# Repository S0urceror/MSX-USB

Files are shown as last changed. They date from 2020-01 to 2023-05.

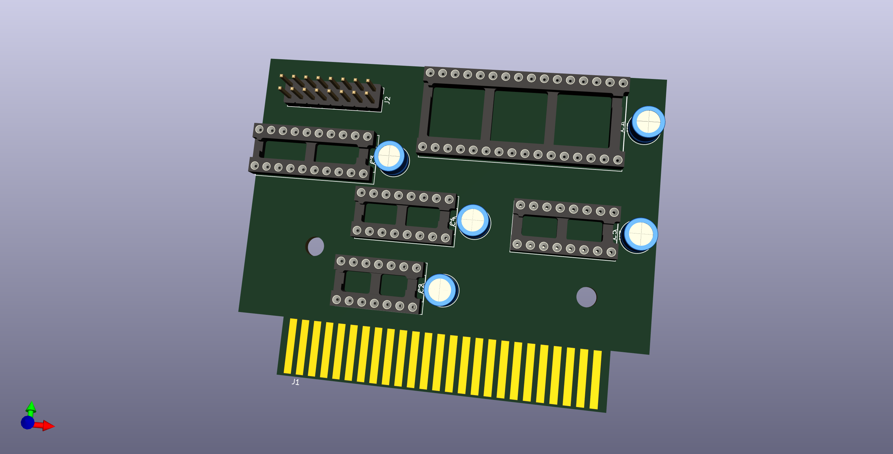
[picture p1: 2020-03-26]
hardware/discontinued/kicad-discrete/MSX USB Drive.png

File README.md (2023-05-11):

# MSX-USB
## Some history
In the 80's the MSX standard was created by Kazuhiko Nishi. He envisioned a simple yet powerful home computer based on standard hardware, software (BIOS/MSX DOS) and connectivity. From 1983 to 1990 manufacturers, like Philips, Sony, Yamaha, Sharp, Canon and many more, made computers according to this standard.

Because of the fact that extensibility was part of the standard people could design cartridges that would add synthesizer sound, memory, modems, rom-based games, or combinations of the above.

Cartridges were connected via a standard 50pin connector that remained the same accross 4 generations of MSX (1/2/2+/TurboR). BIOS and MSX-DOS were designed in a way to discover these via rom-based drivers, software hooks, extended bios.

Standardisation offers a big advantage because everything that adheres to the standard can connect to it.

## USB
USB was designed in the 90's to do something similar. To standardize the connection of peripherals to personal computers, both to communicate with and to supply electric power. It has now largely replaced interfaces such as serial ports and parallel ports, and has become commonplace on a wide range of devices. Like USB flash drives, keyboards, mice, wifi, serial, camera's, etc.

What if the MSX would have an USB connection? And if the BIOS/MSX DOS would automatically recognize devices connected to it?

## Meet MSX-USB
Inspired by the work of Xavirompe and his [RookieDrive](http://rookiedrive.com/en/) I set out to do exactly this. And since I'm a big believer of open standards and open source I'm opening up my work to everyone.

On this GitHub page you can find:
* Schematics (KiCAD), that interfaces a cheap USB CH376s board to the MSX cartridge port.
* Drivers, currently Flash drives on Nextor and HID keyboards are supported.
* Debugging tools, to connect a test board to your PC/MAC and assist in debugging.

On my GitHub I also have forks of OpenMSX and CocoaMSX that either emulate or connect to a test board via serial to assist in development and debugging.

## Schematics
This connects the CH376s board you can find on eBay or AliExpress for around 4 Euro to the MSX. 

Circuitry is added to correctly handle the _BUSDIR signal. Make sure you select parallel by setting the jumper on the CH376s board correctly.

The CH376s board will be visible on port 10h and 11h on the MSX. Port 11h is the command port and 10h is the data port. Specifics on how to program for the CH376s are scattered around the Internet:
* https://www.mpja.com/download/ch376ds1.pdf
* https://arduinobasics.blogspot.com/2015/05/ch376s-usb-readwrite-module.html

Most information is available on how to use the higher-order API for flash drives. 

If you want to use other USB devices you have to go low-level. As it turns out Konamiman already did some work there and after some researching I got USB HID Keyboards, Ethernet, Serial working as well. Check out my source-code or these great pages for more information:
* http://www.usbmadesimple.co.uk/index.html
* https://www.beyondlogic.org/usbnutshell/usb1.shtml

## PCB
Please use the rev4 PCB by @cristianoag. This fits in a Konami style cartridge case and has a switch to select between two ROM images. Also use the rev4 CPLD code to enable this feature.

## UNAPI USB
I wrote a UNAPI USB specification and implemented the Usb Host driver according to this. The next version of this Host driver will also implement the Usb Hub specification and enumerate and initialise all devices connected.

## USB HID Keyboard
The Usb Keyboard driver connects to Unapi Usb driver and hooks itself to H.CHGE. From that moment on it replaces your trusted MSX keyboard by a shiny new USB Keyboard. Or a wireless one if you have inserted the appropriate Logitech receiver.

## USB CDC ECM Ethernet
The USB CDC ECM Ethernet driver is finished. It uses the Unapi USB and conforms to the Unapi Ethernet standard. Internestor Lite can now connect and use your USB Ethernet device. Please note that currently we only support USB CDC ECM. Make sure your Ethernet device supports this.

All USB Ethernet devices built around the **RTL8153** chipset support USB CDC ECM. They usually cost around 20 euro.

## USB Storage
A low level USB driver is created to connect to storage devices like thumb drives, portable hard disks, etc. 

## USB Hub
The USB Hub driver will interrogate an USB Hub and all devices connected to it.

# Installation instructions
Check [this page](INSTALL.md) for installation instructions and links to the various binaries that have been developed.

# Build your own (DIY)
Check [this page](DIY.md) for information on how to make the PCB, program the CPLD device, flash the ROM, etc.

# Collaboration
Do you want to help with the development of MSX USB? Write drivers for other devices? Or contribute in other ways?

Please drop me line on sourceror at neximus.nl or meet me on the msx.org forum.

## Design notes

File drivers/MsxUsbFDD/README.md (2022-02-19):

## Usage
This is a Nextor driver programmed in C. It mounts the USB disk connected to the MSXUSB cartridge. Other devices and USB hubs are not supported by this driver.

### Disk formats supported
1. FAT32
    - Format in Windows, MacOS, Linux with master boot record. 
    - Place .DSK floppy images in the root folder or subfolders. 
    - Select the right DSK file during MSX boot.
2. FAT16
    - Format in Windows, MacOS, Linux with master boot record. 
    - Place .DSK floppy images in the root folder or subfolders. 
    - Select the right DSK file during MSX boot. 
    - **NEXTOR can also mount the whole USB drive in FAT16 mode**
3. FAT12
    - Format in MacOS, Linux or by DD-ing a DSK file to the USB drive. 
    - You will waste a lot of space because now the USB drive can only contain 720kb.

### MSX compatibility
On MSX 1 you can only mount FAT12 720kb DSK images. On MSX 2 and higher you can mount FAT16 DSK images of various sizes or the whole USB disk when formatted in FAT16.

### AUTOEXEC.DSK
Place a disk image called AUTOEXEC.DSK in the root of the USB drive to mount this image automatically. If your press ESCape within 3 seconds it will show the normal boot menu.

### CALL MOUNTDSK
In MSX Basic you can use the _MOUNTDSK or CALL MOUNTDSK command to show the boot menu again and change to another DSK image. Just like changing a floppy would.

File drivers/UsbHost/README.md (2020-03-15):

# USB - Host UNAPI DRIVER
Below the specification of an UNAPI compliant USB driver. Other, more specialised, drivers can rely on this base driver to return the basic information and low-level routines.

## API Information Routine (UNAPI:0)
```
Input: A = 0

Output:
* HL = Address of the implementation name string
* DE = API specification version supported. D=primary, E=secondary.
* BC = API implementation version. B=primary, C=secondary.
```

## JumpTable (UNAPI:1)
This function will return the jumptable to the USB functions to be directly called. 
Every jumptable entry of 8 bytes has the following proposed format. 
Although this can be changed by the UNAPI driver if necessary.
```
Input: A = 1
       HL = pointer to buffer to receive the jumptable
```
UNAPI in ROM:
```
00: RST 30h
01: DB SlotID
02: DW Address
04: RET
05: NOP
06: NOP
07: NOP
```
UNAPI in MemoryMapper:
```
00: CALL CALLS
03: DB Segment
04: DW Address
06: RET
07: NOP
```
Or in PAGE 3:
```
00: JP Address
03: NOP
04: NOP
05: NOP
06: NOP
07: NOP
```
### The functions returned are:
To call a function just do a call to one of the addresses in the jumptable.
Drivers are specifically written to be in ROM, Mapped Ram or Page 3. 
By using this jump table approach, the burden for handling all the specific cases is shifted back from the client to the driver itself. 
This is contrary to the initial UNAPI approach where slot, segment, address is returned by the EXTBIO call, and it is expected by the client to adapt to this.
```
HL+0000: Check
HL+0008: Connect
HL+0010: GetDescriptors
HL+0018: ExecuteControlTransfer
HL+0020: DataInTransfer
HL+0028: DataOutTransfer
HL+0030: ScratchArea
HL+0038: SetNAKRetry
```
## Check (UNAPI:2/JT:00h)
Check if specialised USB hardware is present, like RookieDrive or MSXUSB cartridge.
```
Input:  A = 2
Output: Cy = 0, everything okay, Cy = 1, adapter not ready
```

## Connect (UNAPI:3/JT:08h)
Connect the inserted USB device, reset it properly and prepare for communication.
```
Input:  A = 3
Output: Cy = 0, everything okay, Cy = 1, device not connected
```

## GetDescriptors (UNAPI:4/JT:10h)
Return both the fixed length DEVICE_DESCRIPTOR followed by the variable length CONFIGURATION_DESCRIPTOR containing INTERFACE_DESCRIPTORS, ENDPOINT_DESCRIPTORS and specialised descriptors for HID, CDC ECM, etc.
```
Input: A = 4
       HL = buffer to hold the descriptor information
```

## ExecuteControlTransfer (JT:18h)
Perform a USB control transfer on endpoint 0. The size and direction of the transfer are taken from the contents of the setup packet.
```
Input:  HL = Address of a 8 byte buffer with the setup packet
        DE = Address of the input or output data buffer
        A  = Device address
        B  = Maximum packet size for endpoint 0
Output: A  = USB error code
        BC = Amount of data actually transferred (if IN transfer and no error)
```
## DataInTransfer (JT:20h)
Perform a USB data IN transfer.
```
Input:  HL = Address of a buffer for the received data
        BC = Data length
        A  = Device address
        D  = Maximum packet size for the endpoint
        E  = Endpoint number
        Cy = Current state of the toggle bit
Output: A  = USB error code
        BC = Amount of data actually received (only if no error)
        Cy = New state of the toggle bit (even on error)
```
## DataOutTransfer (JT:28h)
Perform a USB data OUT transfer.
```
Input:  HL = Address of a buffer for the data to be sent
        BC = Data length
        A  = Device address
        D  = Maximum packet size for the endpoint
        E  = Endpoint number
        Cy = Current state of the toggle bit
Output: A  = USB error code
        Cy = New state of the toggle bit (even on error)
```
## ScratchArea (JT:30h)
Get a pointer to the scratch area allocated by moving HIMEM down. Scratch area is used to store USB command packages and a bit of reserved space.
```
Input:  BC = delta in bytes should >0 and < size of scratch area (8*8 bytes currently)
Output: HL = pointer to scratch area in page 3
```

## SetNAKRetry (JT:38h)
Tell USB interface how to handle NAK's. NAK's mostly happen when the device is not yet ready. 
By default the CH376s hardware will automatically retry NAK's until the device is ready and gives back the requested data. But what if the device takes a long time? This will potentially lead to a blocking operation. If you want to avoid this you can set retry's to off or to 3 seconds.
```
Input:  A = retry mode
        Bits 7 and 6:
          0x: Don't retry NAKs
          10: Retry NAKs indefinitely (default)
          11: Retry NAKs for 3s
        Bits 5-0: Number of retries after device timeout
        Default after reset and SET_USB_MODE is 8Fh
Output: (none)
```

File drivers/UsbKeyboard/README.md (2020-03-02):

# Usb Keyboard
The USB Keyboard driver will automatically find the Unapi Usb driver and connect with it. It then checks if a HID compliant keyboard is connected. After that it will start it's resident portion that hooks itself to H.CHGE.

After this the keyboard will work within Basic and DOS and will replace the built-in keyboard. 
Software (games) that don't use BIOS for keyboard will continue to work on the built-in keyboard of the MSX.

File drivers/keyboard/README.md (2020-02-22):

# USB-HID-MSX - MSX driver for USB HID keyboards

USB-HID uses low level execute-command sequences for all common USB and USB HID communication via CH376.

Load the current version via BLOAD "driver.bin",r

It will find the connected USB HID keyboard, activate it's BOOT protocol, and installs the H.CHGE hook. After this the normal keyboard won't work anymore. The HID keyboard takes over. 

When you press ALT+Q the hook is deinstalled and the MSX keyboard works again.

## Limitations
* special keys like STOP and GRAPH not yet implemented
* should automatically start with the computer from ROM
* work in progress...

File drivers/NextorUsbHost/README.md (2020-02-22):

# USB Flash Drive
Once flashed Nextor ROM will automatically find the driver and initialise the CH376s.
Then it searches the file identified by TXT_NEXTOR_DSK and mounts it. 
It then continuous to boot. 
* If there is NEXTOR.SYS and COMMAND2.COM on the mounted disk it will start NEXTOR.
* If there is MSXDOS2.SYS and COMMAND2.COM on the mounted disk it will start MSXDOS2.x
* If there is MSXDOS.SYS and COMMAND.COM it will start MSXDOS1.x
* Otherwise it goes to MSX BASIC

In MSX Basic you have the following commands:
* CALL USBFILES - list all files in the current directory of the FAT32 formatted flash drive
* CALL USBCD - change to another directory of the flash drive
* CALL INSERTDISK ("filename.ext") - load another disk image and mount it
* CALL EJECTDISK - eject the current mounted disk image

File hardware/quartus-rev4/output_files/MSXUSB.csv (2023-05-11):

# Copyright (C) 1991-2011 Altera Corporation
# Your use of Altera Corporation's design tools | logic functions
# and other software and tools | and its AMPP partner logic
# functions | and any output files from any of the foregoing
# (including device programming or simulation files) | and any
# associated documentation or information are expressly subject
# to the terms and conditions of the Altera Program License
# Subscription Agreement | Altera MegaCore Function License
# Agreement | or other applicable license agreement | including
# without limitation | that your use is for the sole purpose of
# programming logic devices manufactured by Altera and sold by
# Altera or its authorized distributors. Please refer to the
# applicable agreement for further details.
# Quartus II Version 11.0 Build 208 07/03/2011 Service Pack 1 SJ Web Edition
# File: C:/Users/crist/OneDrive/Personal/11. Electronics/MSXUSB/GitHub/MSX-USB.crisag/hardware/quartus-rev3/output_files/MSXUSB.csv
# Generated on: Wed Nov 23 20:26:52 2022
# Note: The column header names should not be changed if you wish to import this .csv file into the Quartus II software.
To | Direction | Location | Reserved
TCK | Input
TDI | Input
TDO | Output
TMS | Input
busdir | Output | PIN_6
cs_ch376s_n | Output | PIN_5
data[5] | Input | PIN_8
data[4] | Input | PIN_9
data[3] | Input | PIN_11
data[2] | Input | PIN_12
data[1] | Input | PIN_14
data[0] | Input | PIN_16
in_a7_a0[7] | Input | PIN_18
in_a7_a0[6] | Input | PIN_19
in_a7_a0[5] | Input | PIN_20
in_a7_a0[4] | Input | PIN_21
in_a7_a0[3] | Input | PIN_24
in_a7_a0[2] | Input | PIN_25
in_a7_a0[1] | Input | PIN_26
in_a7_a0[0] | Input | PIN_27
in_a15_a13_a12[2] | Input | PIN_28
in_a15_a13_a12[1] | Input | PIN_29
in_a15_a13_a12[0] | Input | PIN_17
iorq_n | Input | PIN_4
out_a13_a18[5] | Output | PIN_31
out_a13_a18[4] | Output | PIN_33
out_a13_a18[3] | Output | PIN_34
out_a13_a18[2] | Output | PIN_36
out_a13_a18[1] | Output | PIN_37
out_a13_a18[0] | Output | PIN_39
rd_n | Input | PIN_1
reset_n | Input | PIN_44
rom_sl | Input | PIN_2
sltsl_n | Input | PIN_41
wr_n | Input | PIN_40

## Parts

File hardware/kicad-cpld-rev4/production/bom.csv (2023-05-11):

Designator | Footprint | Quantity | Value | LCSC Part #
C1 | CP_Radial_D5.0mm_P2.50mm | 1 | 100 uF
C2, C3, C4 | C_0805_2012Metric_Pad1.18x1.45mm_HandSolder | 3 | 0.1 uF
EDG1 | msx-con-MSXCART | 1 | MSX_CON
J1 | PinHeader_2x05_P2.54mm_Vertical | 1 | AVR-JTAG-10
J2 | PinHeader_2x08_P2.54mm_Vertical | 1 | Conn_02x08_Odd_Even
LOGO_MSX | LOGO_MSX | 1
R1 | R_0805_2012Metric_Pad1.20x1.40mm_HandSolder | 1 | 4K7
SW1 | SK12D07VG4 | 1 | SK12D07VG4
U1 | PLCC44 | 1 | EPM7032_7064
U2 | PLCC-32_THT-Socket | 1 | AM29f040

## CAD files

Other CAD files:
hardware/quartus-rev4/simulation/modelsim/rtl_work/ch376/verilog.psm
hardware/quartus-rev4/simulation/modelsim/rtl_work/msxusb/verilog.psm
hardware/quartus-rev4/simulation/modelsim/rtl_work/scc_rom_mapper/verilog.psm
hardware/quartus-rev4/simulation/modelsim/rtl_work/t_ch376/verilog.psm
hardware/quartus-rev4/simulation/modelsim/rtl_work/t_scc_rom_mapper/verilog.psm

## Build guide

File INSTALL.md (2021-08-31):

# MSX-USB
## Installation instructions
You have to flash a new NEXTOR ROM image onto a MSX flash cartridge. The RookieDrive and other MSX USB initiatives have both Flash and the USB part combined in one cartridge so thats easy. In my prototype setup I have one cartridge with MSX USB and one modded SCC cartridge with flash and that works as well.

You can use the MSX USB cartridge in two modes.

### Use as disk drive
* Download [this](https://github.com/S0urceror/MSX-USB/raw/master/drivers/NextorUsbHost/dist/nextor.rom) ROM image
* Flash the image
* Reboot

The first time you need to boot up with a floppy disk with the NEXTOR.SYS and COMMAND2.COM files. 
Please insert a FAT16 formatted USB Flash Disk in the MSX USB cartridge.
Put NEXTOR.SYS and COMMAND2.COM in the root of that disk. Insert into the MSX and go.

*N.B. if you want to use MSXUSB on the [RookieDrive](http://rookiedrive.com/en/) please use [this](https://github.com/S0urceror/MSX-USB/raw/master/drivers/NextorUsbHost/dist/nextorrd.rom) version of the ROM.*

### Multi purpose USB port
The ROM image now also contains an UNAPI compatible USB Host driver.

You can do the following things:
* [APILIST.COM](https://github.com/S0urceror/MSX-USB/raw/master/drivers/UsbEthernet/dist/apilist.com) MSXUSB to check that the UNAPI driver is ready and works.
* [LSUSB.COM](https://github.com/S0urceror/MSX-USB/raw/master/drivers/UsbEthernet/dist/lsusb.com) to list all technical USB information from the connected USB device.
* [USBETHER.COM](https://github.com/S0urceror/MSX-USB/blob/master/drivers/UsbEthernet/dist/usbether.com) to install the USB Ethernet Driver. You can then subsequently run `INL i` to install Internestor Lite. When all goes well you can then run any TCP/IP applications like `TELNET`, `HUB`, `HGET`, `TFTP`, etc. More information about this you can find on [Konamiman's](https://www.konamiman.com/msx/msx-e.html#inl2) website.
* BLOAD ("[USBKEYBD.BIN](https://github.com/S0urceror/MSX-USB/raw/master/drivers/UsbKeyboard/dist/usbkeybd.bin)"),R to install the USB HID Keyboard driver. This will enable any connected USB HID compliant keyboard.

## Flashing the image
To flash the ROM's you need an appropriate flashing tool. For this I created a program called Flash. You can download it [here](https://github.com/S0urceror/MSX-USB/raw/master/software/dist/flash.com)

It is simple to use Flash. The following statement automatically finds the (mega-)flash cartridge and flashes image.rom.

`FLASH nextor.rom`

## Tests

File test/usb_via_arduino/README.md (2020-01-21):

# usb-hid
USB-HID uses low level execute-command sequences for all common USB and USB HID communication via CH376. 

The CH376s has higher level commands for GET_DESCRIPTOR, SET_ADDRESS but they are limited to 64 byte packet-size.
By using low-level command sequences we can read the larger  descriptors that are typical for HID devices. 
Particulary the Logitech USB Receivers that I intend to use.

Is currently able to discover attached keyboards and mice.

This simple C/C++ program is just a tester to move this functionality to a MSX driver. 
Yes, this illustrious computing system from the 80's finally gets USB connectivity.

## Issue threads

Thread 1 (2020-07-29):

Fail Rom flash AM29F040

retrocant, 2020-07-29:
Greetings, I am having problems recording the msx-usb flashrom, it gives me the following error:

MSXUSB Flash, (c) 202 S0urceror

M: E5, D: CD
M: CD, D: AB
M: F0, D: 1F
M: FF, D: FF

cannot find slot with flash

I am doing the flash method through the MegaFlashrom

S0urceror, 2020-07-29:
Hi Retrocant,

My routine expects to find:

// Am29F040B = A4

// M29F800AB = 58

// SST39SF040 = B7

These are all 4Mbit/512KB flash ROM’s. Could be that you have the AM29F400BB that has device code ‘AB’ in your 2nd line.

To force flashing on slot 1 use:

flash.com /S1 [filename]

Can you confirm it works then I’ll add AB to my identification routine.

Thanks,

S0urceror

From: retrocant <notifications@github.com>
Reply to: S0urceror/MSX-USB <reply@reply.github.com>
Date: Wednesday, 29 July 2020 at 17:00
To: S0urceror/MSX-USB <MSX-USB@noreply.github.com>
Cc: Subscribed <subscribed@noreply.github.com>
Subject: [S0urceror/MSX-USB] Fail Rom flash AM29F040 (#1)

Greetings, I am having problems recording the msx-usb flashrom, it gives me the following error:

MSXUSB Flash, (c) 202 S0urceror

M: E5, D: CD
M: CD, D: AB
M: F0, D: 1F
M: FF, D: FF

cannot find slot with flash

I am doing the flash method through the MegaFlashrom

—
You are receiving this because you are subscribed to this thread.
Reply to this email directly, view it on GitHub, or unsubscribe.

retrocant, 2020-07-30:
Greetings, I already did the flash / s1 NEXTOR.ROM routine and it doesn't work either, it gives me the same error.

Greetings.

S0urceror, 2020-07-30:
Which MSXUSB cartridge did you make? The CPLD version? Did you use the latest design or the first design? The first design had two issues that you can easily solve with a couple of wires.

On the other hand what type/version of Flash chip have you installed? The AM29F040?

If you have the RookieDrive make sure you use the flash tool that came with that cartridge because it uses another ROM mapper and other Flash chip.

From: retrocant <notifications@github.com>
Reply to: S0urceror/MSX-USB <reply@reply.github.com>
Date: Thursday, 30 July 2020 at 18:18
To: S0urceror/MSX-USB <MSX-USB@noreply.github.com>
Cc: Mario Smit <mario.smit.nl@gmail.com>, Comment <comment@noreply.github.com>
Subject: Re: [S0urceror/MSX-USB] Fail Rom flash AM29F040 (#1)

Greetings, I already did the flash / s1 NEXTOR.ROM routine and it doesn't work either, it gives me the same error.

Greetings.

—
You are receiving this because you commented.
Reply to this email directly, view it on GitHub<https://github.com/S0urceror/MSX-USB/issues/1#issuecomment-666501659>, or unsubscribe<https://github.com/notifications/unsubscribe-auth/ABGC6KCOS5NVSOIFTGZYSLTR6GMOBANCNFSM4PLV7PHQ>.

retrocant, 2020-07-31:
Greetings, I have the CPLD version, I don't know if there were two different versions in that version ... how could I know?

I use FLASH AM29F040

retrocant, 2020-07-31:
I just made the two bridges for the SLTSL and RD and it keeps giving me the same error, it doesn't flash me

S0urceror, 2020-08-02:
Your PCB is the rev.1 version. There were two flaws in this. One was with RD and SLTSL reversed. The other was that A12 was not connected to the CPLD.

Have you also have created an extra bridge between Flash pin 4 and CPLD pin 17?

From: retrocant <notifications@github.com>
Reply to: S0urceror/MSX-USB <reply@reply.github.com>
Date: Friday, 31 July 2020 at 19:51
To: S0urceror/MSX-USB <MSX-USB@noreply.github.com>
Cc: Mario Smit <mario.smit.nl@gmail.com>, Comment <comment@noreply.github.com>
Subject: Re: [S0urceror/MSX-USB] Fail Rom flash AM29F040 (#1)

I just made the two bridges for the SLTSL and RD and it keeps giving me the same error, it doesn't flash me

—
You are receiving this because you commented.
Reply to this email directly, view it on GitHub<https://github.com/S0urceror/MSX-USB/issues/1#issuecomment-667252912>, or unsubscribe<https://github.com/notifications/unsubscribe-auth/ABGC6KC3DYDCCSX43HZXVRLR6MADHANCNFSM4PLV7PHQ>.

retrocant, 2020-08-06:
Greetings, I already made the bridge in the CPLD and it works, I did not know about that bridge, I have it functional.

Now I have a question, there are two versions 0.5 and 0. release.

I have an 8GB FAT32 USB flash drive, version 0.5 works fine and it recognizes the flash drive, but version 0.6 does not recognize the USB.

S0urceror, 2020-08-07:
Hi Retrocant,

Glad and good to hear that you have it working!

Until 0.5 the driver used the built-in FAT32 support of the CH376s chip. Starting 0.6 I implemented a low-level USB storage driver that also works behind an USB Hub. Now I have to rely on the FAT16 support of Nextor instead. If you reformat your drive to FAT16 it will work again with the added bonus it will also work on a Hub together with other USB devices.

That said, I could check what you have connected, if you have directly connected a USB storage device with FAT32, use the built-in driver, or otherwise fallback on my own storage driver that supports Hubs with FAT16. Would be a nice feature for a next release.

Regards,

Mario

From: retrocant <notifications@github.com>
Reply to: S0urceror/MSX-USB <reply@reply.github.com>
Date: Thursday, 6 August 2020 at 20:11
To: S0urceror/MSX-USB <MSX-USB@noreply.github.com>
Cc: Mario Smit <mario.smit.nl@gmail.com>, Comment <comment@noreply.github.com>
Subject: Re: [S0urceror/MSX-USB] Fail Rom flash AM29F040 (#1)

Greetings, I already made the bridge in the CPLD and it works, I did not know about that bridge, I have it functional.

Now I have a question, there are two versions 0.5 and 0. release.

I have an 8GB FAT32 USB flash drive, version 0.5 works fine and it recognizes the flash drive, but version 0.6 does not recognize the USB.

—
You are receiving this because you commented.
Reply to this email directly, view it on GitHub<https://github.com/S0urceror/MSX-USB/issues/1#issuecomment-670092006>, or unsubscribe<https://github.com/notifications/unsubscribe-auth/ABGC6KEELN3MDLWHQJRXGH3R7LW35ANCNFSM4PLV7PHQ>.

S0urceror, 2021-09-07:
Closing this issue, good that we traced the problem down to the reversed OE (output enable) and CE (chip enable). The latest published PCB with the clearly marked v1.0 on the silkscreen does not have this problem.

issalig, 2022-02-19:
I cannot make it work. Tested on MSX1 VG-8020  with a pcb v1.0 and also other people reported similar problem with MSX2 f9s

I use a SST39SF040 which should give id BF B7 and I am getting these values

E5 CD
41, 42
41, 42
F0, 0

I checked the codes on http://www.cnc-lab.com/idcodes.txt and they does not seem to fit any IC.

Any idea?

S0urceror, 2022-02-19:
Hi Issalig,

I made an earlier mistake in my PCB which I corrected in an updated design pushed to GitHub.

SLTSL from the cartridge port should be connected to CE (pin 22) and RD from the cartridge port should be connected to OE (pin 24) of the flash chip. Can you verify this with a multi-meter?

You now get 0x41,0x42 on slot 1 and 2. This means there are MSX roms read. A flash however should respond with the manufacturer codes which it doesn’t do now.

Let me know the result.

Regards,

Mario

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

issalig, 2022-02-19:
pcb is ok. CE nad OE are connected to SLTSL and RD

I tried to change bytecodes
AM takes 0x555 and 0x2aa
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

and SST 0x5555 and 0x2aaa
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

Results are different now, but still does not work
E5 CD
FE, 5E    <---- this was 41,42, the others are the same
41, 42
F0, 0

S0urceror, 2022-02-20:
You’re on the right path.

Can’t test it here but if you:

  *   Change the __at 0x4000 statement to __at 0x0000 at line 30.
  *   Update all places where flash_segment is used with the right addresses.
  *   Write 0xAA to flash_segment[0x5555]
  *   Write 0x55 to flash_segment[0x2AAA]
  *   Write 0x90 to flash_segment[0x5555]
  *   Read manufacturer from flash_segment[0x0000]
  *   Read device from flash_segment[0x0000]

Then it should show you 0xBF, 0xB5 respectively.

Also the erase and flash routines have to be updated with the other addresses.

P.S. would be great to have all this governed by #defines and -D arguments in the Makefile. This way we can make multiple versions of the flash.com program each for every flash chip.

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

issalig, 2022-02-20:
Changing to 0x0000 and new adresses does not help. It prints the first 2 slots, then hangs for a little bit and restarts system without detecting msxusb

F0, D3
F0, D3
...
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
issalig, 2022-02-24:
Thanks for the explanation. I am getting a better picture of the situation and I did the changes but the code does not still work and it hangs when scanning slot 2.

Let's try to understand it, flash_segment points to address 0x4000 (page 1, after system rom).
Next, select_slot_40 selects page 1 on slot i, that means we have access to flash chip on msx memory addresses 4000-7ffff
The same is done for slot_80 and msx addresses 8000-BF000

So flash_segment[0] points to 0x4000 that itself points to 0x4000 in slot i (aka our cartridge).

We need to access flash address 0x5555 which resides in the page 1 (4000-7fff) and flash_segment points to 4000. Would not flash_segment[0x1555] be the indirect address to arrive to internal 0x5555 ?

If this is correct, then 0x2aaa could not be reached but I am almost sure I misunderstood sth.

S0urceror, 2022-02-24:
I am commenting below:

> Let's try to understand it, flash_segment points to address 0x4000 (page 1, after system rom). Next, select_slot_40 selects page 1 on slot i, that means we have access to flash chip on msx memory addresses 4000-7ffff The same is done for slot_80 and msx addresses 8000-BF000

That is correct.

> So flash_segment[0] points to 0x4000 that itself points to 0x4000 in slot i (aka our cartridge).

It points indeed to 0x4000 to slot i. But what ROM page is mapped there? That depends on a previous write to 0x5000. This triggers the FPGA to select page 0 which is address range 0x00000 to 0x04000. So from now on a write to a CPU address of 0x6aaa is actually targeting flash address 0x02aaa.

> We need to access flash address 0x5555 which resides in the page 1 (4000-7fff) and flash_segment points to 4000. Would not flash_segment[0x1555] be the indirect address to arrive to internal 0x5555 ?

If as stated above the CPU address range 0x4000 to 0x7fff points to page 0 being flash range 0x00000 to 0x03fff and we make sure that CPU address range 0x8000 to 0xbfff points to page 1 being flash range 0x04000 to 0x07fff. Then we need to write to CPU address 0x9555 to write to flash address 0x05555.

I'll try to test the above theory out and report back. This would enable you to address 32k of the flash and reach all the addresses the flash-ident and flash-write routines need to function.

issalig, 2022-02-26:
Looking at the verilog scc code I see that when a write is detected, the values of a15,a13,a12  establish the following addresses.
| A15 | A14 | A3 | A12 |
|  0    |  ?    |   0  |     1  |   1XXX, 5XXX
|  0    |  ?    |   1  |     1  |   3XXX , 7XXX
|  1    |  ?    |   0  |     1  |   9XXX , DXXX
|  1    |  ?    |   1  |     1  |   BXXX , FXXX

In a similar way a read gives

| A15 | A14 | A3 | A12 |
|  0    |  ?    |   0  |     ?  |   0XXX, 1XXX*, 4XXX, 5XXX*
|  0    |  ?    |   1  |     ?  |   2XXX , 3XXX*, 6XXX, 7XXX*
|  1    |  ?    |   0  |     ?  |   8XXX , 9XXX*, CXXX, DXXX*
|  1    |  ?    |   1  |     ?  |   AXXX , BXXX*, EXXX, FXXX*

(*) the ones for write.

So for example a write to 0x5000=0 will put mem0 into address_upper and data into mem0
address_upper are the pins A18-A13   and data will be 0 in this case.

```
case(a15_a13_a12[2:1])
			2'b00: address_upper = mem0;
```
```
case(a15_a13_a12)
   3'b001: mem0 = data;
```
I checked the addresses below with the ones in https://www.msx.org/wiki/MegaROM_Mappers#Konami.27s_MegaROMs_with_SCC
and I am lost at this point. I must find some documentation for dummies because reverse engineering this from code will take me years.

Closed 2021-09-07.

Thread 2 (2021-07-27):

Minified pcb (my build log)

issalig, 2021-07-27:
Hi, thanks for sharing the project. I am new to the MSX world and I am working on a minified pcb with plcc sockets and exposed headers for future developement (as soon as everything works I will update my fork). Board will be 5 cm high.

I have some doubts about the bill of materials, the cpld is epm7064 or epm7032? SLC44 or LC44?
The memory could it be SST39SF040-70 or  SST39SF040-55?

Maybe there is a BOM file and I did not find but it would be nice to have it also with some alternative components.

Thanks in advance

S0urceror, 2021-07-28:
Hi Issalig,

Interesting project. Minified PCB. Let me know how it goes.

Regarding the BOM. I have generated one with KiCAD. You can find it enclosed.

The CPLD is a EPM7064 in a PLCC-44 housing. The flash you can use anyone that is compatible to the pins. Basically every flash that conforms to the JEDEC standard you can use. Only in programming the flash you have to use another routine. If you program in a separate programmer then this is not an issue.

Regards,

Mario

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

issalig, 2021-07-28:
Thanks for the quick answer, I am going to order the components now.

issalig, 2021-08-13:
I have received the PCB but still some components are on their way. Looking fwd to test it all and hopefully without magic smoke :)

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

S0urceror, 2021-08-14:
Nice. Congratulations on the design. Hope it all works fine.

Sent by phone
________________________________
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

issalig, 2021-09-03:
I will use this issue for now as my building log.

I have all the components but I am totally lost, I suppose I have to program the CPLD and flash the memory but I can't find the proper files.

Is the memory file https://github.com/S0urceror/MSX-USB/blob/master/software/flash/dist/flash.com  ?
I think I can program it with tl866

And now the difficult part to me (never programmed a CPLD)
I see you used Quartus software, is there an open source alternative?
Do I need a special programmer? Which one do you recommend?

As far as I guess,  this is the file I have to write in the CPLD https://github.com/S0urceror/MSX-USB/blob/master/hardware/quartus/output_files/MSXUSB.pof
and it could be done by command line $ quartus_pgm -m jtag -o "p;MSXUSB.pof"

Thanks in advance and sorry for so many questions.

mario-smit-heroes, 2021-09-06:
Hi Issalig,

You have to do two things:

1. Program the CPLD. For this you have to use Quartus. You can download a free version from Intel. Download the one (older version) that supports this chip. There is no open source version. You don’t have to build you can program the POF file. You do this by connecting the JTAG connector to an Altera compatible USB Blaster device. You can find cheap ones on eBay. Make sure you also connect 5v and GND to the PCB when you do this. Easiest to do this is to connect to the relevant pins of the CH376 connector.
2. Program the Flash chip. You can use flash.com for this from inside the MSX and use the Nextor.rom file. You can also use an USB EPROM programmer for this.
3.

Once this is done you should have a functioning cartridge and start Nextor and use USB devices.

S0urceror, 2021-09-07:
Hi Issalig,

You have to do two things:

1. Program the CPLD. For this you have to use Quartus. You can download a free version from Intel. Download the one (older version) that supports this chip. There is no open source version. You don’t have to build you can program the POF file. You do this by connecting the JTAG connector to an Altera compatible USB Blaster device. You can find cheap ones on eBay. Make sure you also connect 5v and GND to the PCB when you do this. Easiest to do this is to connect to the relevant pins of the CH376 connector.
2. Program the Flash chip. You can use flash.com for this from inside the MSX and use the Nextor.rom file. You can also use an USB EPROM programmer for this.

Once this is done you should have a functioning cartridge and start Nextor and use USB devices. Let me know how it goes.

issalig, 2021-09-07:
Thanks for the explanation. I am waiting for the programmer (let's hope it will be here in 2 weeks).

Looking fwd to explore the MSX world (which is new to me) and test my nice VG-8020

issalig, 2021-09-21:
Programmer finally arrived. I got a dirty cheap one https://aliexpress.com/item/1005002674193901.html

I tried directly and got this error
./quartus_pgm -m jtag -o "p;MSXUSB.pof"
Error (213019): Can't scan JTAG chain. Error code 89.

That can be better diagnosed
./quartus --auto
...
1) USB-Blaster variant [3-1]
  Unable to lock chain (Insufficient port permissions)
..

So we need to add the needed rules to file /etc/udev/rules.d/37-usbblaster.rules
```
SUBSYSTEM=="usb", ATTRS{idVendor}=="09fb", ATTRS{idProduct}=="6001", GROUP="plugdev", MODE="0666", SYMLINK+="usbblaster"
```
And then
```
sudo service udev restart
```

Then the following error appear
./quartus_pgm -m jtag -o "p;./MSXUSB.pof"
Error (213019): Can't scan JTAG chain. Error code 87.

So I had to power it externally from 5V because for some reason power from programmer was not enough (see this issue for similar problems https://github.com/drandyhaas/Haasoscope/issues/45 )

mario-smit-heroes, 2021-09-21:
Hi Issalig,

Also have a simple programmer from AliExpress. Works good.

I don’t use the command line but use the Quartus UI.

Additional 5v is indeed necessary.

PS. I have some time later this week to check the command line examples you gave. I’ll tell you how that went.

Get Outlook for iOS<https://aka.ms/o0ukef>
________________________________
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

issalig, 2021-09-21:
After building the video cable, it boots but "No enough memory" appears.
I think is sth related to nextor. Well, I will check it later.

issalig, 2021-10-02:
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

issalig, 2021-10-03:
Thanks for the indications @S0urceror, after changing my USB reader, I am a little bit closer
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
Then some random chars
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
And finally date
![Uploading vlcsnap-2021-10-03-10h51m18s248.png…]()

But CALL USBFILES does not say anything
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

S0urceror, 2021-10-03:
Hi Issalig, I guess we're almost there.

I see you're running it on an MSX1 computer. Which one is it? I believe Nextor will then run in MSX-DOS1 mode please put a MSXDOS.SYS and COMMAND.COM in the root of your USB device. Don't know where the characters are coming from. I am running it on my trusty MSX2 computer with a 128kb memory mapper.

I'll do a check on my modded OpenMSX connected to my MSXUSB test board and run the computer image you are having. This would then show the same results I guess.

The different CALL commands are not supported anymore. This was in FAT32 support mode only. In that mode you cannot work with USB hubs and other devices at the same time. The install.md still contained the old text. I have now updated that.

issalig, 2021-10-03:
Yes, it is an MSX1 Philips VG8020

I have put MSXDOS.SYS and results seem the same. But the problem is I do not know how to list the USB contents :(

Thanks for your support, I am totally a noob in MSX world and I am discovering it thanks to MSXUXB :+1:

S0urceror, 2021-10-03:
No problem. You can use the following standard commands in MSX Basic:

FILES lists the contents of the disk/folder
LOAD (“filename”) load a Basic program
BLOAD (“filename”) load a binary

more info here: https://www.msx.org/wiki/Category:Disk_BASIC

Of course these only work when the disk has been recognized and formatted correctly.

I’ll do a test as I described before later this evening CET. I’ll let you know how this goes.

Get Outlook for iOS<https://aka.ms/o0ukef>
________________________________
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

issalig, 2021-10-03:
Thanks, FILES returns Disk I/O Errror

issalig, 2021-12-18:
I close this thread because I have a working pcb.

I have updated my fork https://github.com/issalig/MSX-USB with the gerbers of the minipcb and a DIY guide in the README.md file.

@S0urceror , feel free to include anything you want and again thanks for your project.

Closed 2021-12-18.

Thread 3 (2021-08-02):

About MSX-USB discrete

denjhang, 2021-08-02:
Since it is difficult to buy a working CPLD where I live (EPM7064 and the like, usually bought are fakes), I want to build a discrete version of MSX-USB. I want to know about the current discrete version of MSX-USB Is there any error in the schematic diagram? If so, please point it out, and then I will correct it and make the PCB.

S0urceror, 2021-08-03:
Hi Liu,

The Kicad files on Github for the discrete version should work. I created a prototype board based on this and it still works after 2 years. You have to make your own PCB. My own development is on the CPLD version which is indeed more difficult to make since you need a programmer and the chips.

Let me know how it goes.

Regards,

Mario

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

denjhang, 2021-08-03:
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
The schematic is not connected here, is there a problem?

S0urceror, 2021-08-03:
You’re right. Both WR lines should be connected. I corrected it.
***@***.***

Also, if you want it to be RookieDrive compatible and use the appropriate rom file you can switch A4 and A5 on the 74LS688.

***@***.***

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

denjhang, 2021-08-03:
Then please take a look at how you said A4 and A5 of 74LS688 should be switched, or which ROM I want to use in which circuit.
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

S0urceror, 2021-08-03:
The 74LS688 is a comparator. It enables the communication to the CH376s chip when the address lines and IO request signal are the same as the pins R0 to R7.

Now it is configured to select the I/O at 0x10 or 0b0001000x. You can change this to 0x20 or 0b001000x. The RookieDrive uses 0x20.

The flashROM has nothing to do with this. It just talks with the Z80 on it’s own set of address and datalines.

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

denjhang, 2021-08-03:
I understand, then I don't need the compatibility of RookieDrive at present, can the circuit directly use the ROM linked below?
https://github.com/S0urceror/MSX-USB/raw/master/drivers/NextorUsbHost/dist/nextor.rom

Thank you for your work and reply.

S0urceror, 2021-08-04:
Yes. If you do the RookieDrive compatible setup you use the NextorRD.rom.

Get Outlook for iOS<https://aka.ms/o0ukef>
________________________________
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

S0urceror, 2021-09-07:
Closing this issue for now. Hope you get the discrete version up and running.

Closed 2021-09-07.

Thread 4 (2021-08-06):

Flash.com does not work correctly

denjhang, 2021-08-06:
Currently I use the latest version V1.0 PCB (using EPM7064SLC44-10
) And use MX29F040-70. Found unable to run flash.com correctly.
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

S0urceror, 2021-08-06:
Flash.rom currently only support the AMD flash chips. Other flash chips use different programming instructions. We can support it if I find time to add it to flash.com. In the meantime you can use a separate programming device to flash it.

Btw. nice PCB you made.

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

denjhang, 2021-08-08:
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

I am currently using AM29F040-90PI, and found that the result is the same as before, but still cannot run flash.com correctly.
I directly used the programmer to program the ROM, and found that the msx-basic was directly entered after booting, which means that the program in the ROM did not work. I began to suspect that there was a problem with the SPLD program.
Can you provide the POF firmware file for programming SPLD? I used MSX-USB-master\hardware\quartus\output_files\MSXUSB.pof before, and successfully uploaded the firmware program using USB Blast.

S0urceror, 2021-08-09:
Here the POF I created.

Also included is a ROM file. If you flash that in your programmer you should get the following output. This proves the ROM mapper is working properly. Please send me the output you’re getting.
***@***.***

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

denjhang, 2021-08-09:
What is the following output?

mario-smit-heroes, 2021-08-09:
> What is the following output?

I see that image attachments do not get through. Here is the link:

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

S0urceror, 2021-08-09:
Can you also check the output of flash.com. It tries to find a flash chip manufacturer/device and it prints it. Most likely this is slot 1 or 2.

Compare it with this list: https://chromium.googlesource.com/chromiumos/third_party/flashrom/+/master/flashchips.h

Flash.com does not start flashing if the manufacturer/device id do not match.

You can override this by specifying /Sx where x is the slot number you want to flash.

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

denjhang, 2021-08-09:
I found something wrong. flash.com cannot automatically recognize my ROM anyway. Even using AM29F040-90PI and using commands such as /S2 cannot complete programming correctly.

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

denjhang, 2021-08-09:
It seems that CPLD is not running properly

denjhang, 2021-08-09:
"Here the POF I created.
Also included is a ROM file."

I am very confused, I did not see any files uploaded by you. I can't see the link to the file.

S0urceror, 2021-08-09:
Yes sorry, I am replying from within my email client to the thread on Github. It looks like images and attachments do not make it back to Github. To be able to directly send you files I need your direct email address. Please find my profile Sourceror on msx.org. If you use my email listed there we can email directly and freely exchange files. When we have a solution we’ll post it also on Github so that everyone else can use it.

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

denjhang, 2021-08-09:
I have sent an email, my email is ltj825152013@gmail.com

denjhang, 2021-08-10:
I can make sure to use the files provided in your email (actually I used these two files before). So I more doubt whether there is a problem with the circuit somewhere. I can make sure that I am currently using MSX-USB v1.0 CPLD PCB, but I found the changes mentioned in https://www.msx.org/forum/msx-talk/hardware/msx-usb?page=19 It has not been applied. This is why the ROM mapper somehow was stuck on segment 0. This actually means that the ROM mapper is not working correctly.
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

denjhang, 2021-08-10:
I found that the A12 of the CPLD and ROM on the PCB is disconnected, and there is no connection.

denjhang, 2021-08-10:
In addition, I need you to explain whether this modification is necessary.
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

mario-smit-heroes, 2021-08-11:
If you have no continuity between those pins you need to make a wire bridge as indicated in the post on msx.org.

Get Outlook for iOS<https://aka.ms/o0ukef>
________________________________
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

S0urceror, 2021-08-11:
> I found that the A12 of the CPLD and ROM on the PCB is disconnected, and there is no connection.

Please make a connection as indicated in the msx.org post. That explains what is happening.

S0urceror, 2021-08-11:
> In addition, I need you to explain whether this modification is necessary.
> 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

I’ll check my notes on that later tonight and let you know.

mario-smit-heroes, 2021-08-11:
Btw, I also checked your initial picture and it does not say MSX USB v1.0 on the silk screen.

Like it should:
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

That confirms you need to make a connection like this:
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

mario-smit-heroes, 2021-08-11:
Yes you need to reverse these pins also:
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

This reverses OE (output enable) and CE (chip enable). In the pre v1.0 version I had this wrong. This has no impact on reading from the chip but causes incorrect timing for writing to the chip. Explains that flash.com does not work.

denjhang, 2021-08-11:
I found the problem. Because I am using the gerber from this link: https://github.com/S0urceror/MSX-USB/blob/master/hardware/kicad-cpld/gerber/msxusb.zip
But in fact this file was created more than a year ago.
The other files in the same folder are the ones you created this year.
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

S0urceror, 2021-08-11:
Thanks for pointing it out. I’ll fix the GitHub issues. Also I will update the documentation with the latest info

Get Outlook for iOS<https://aka.ms/o0ukef>
________________________________
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

denjhang, 2021-08-11:
I have placed an order for PCB production of MSX-USB V1.0, this time I can ensure that it is version 1.0, and I chose purple as the color of the PCB solder mask ink.
In fact, I am willing to pay some costs for MSX-USB, because I think this is a very valuable project. Even if I encounter some problems, I have to solve them one by one.

S0urceror, 2021-09-07:
The old version of the PCB had an error which meant you had to swap pins OE (output enable) and CE (chip enable). Without this flash.com does not work. Thanks Denjhang for pointing this out. The latest PCB gerbers correct this and are good. To be sure check the marking v1.0 on the silkscreen.

Closed 2021-09-07.

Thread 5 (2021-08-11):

The link to the dsks.zip file is invalid

denjhang, 2021-08-11:
https://github.com/S0urceror/MSX-USB/blob/master/INSTALL.md
The files under this link are no longer valid, I actually need these three files.
128mb.DSK
720kb.DSK
NEXTOR.DSK

S0urceror, 2021-09-07:
FAT32 support was ceased as explained in the other issue. As a result I don't maintain the .DSK files anymore. Still have them stored somewhere on my machine if you want but you need the old driver to use them.

Closed 2021-09-07.

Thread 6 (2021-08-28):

Cannot use call usbfiles

denjhang, 2021-08-28:
At present, my MSX-USB card can be recognized and run normally, but in the basic interface, all commands with USB are invalid.

denjhang, 2021-08-28:
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

denjhang, 2021-08-28:
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

denjhang, 2021-08-28:
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
This is the result obtained by testing the ROM.

denjhang, 2021-08-28:
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

This is the result of using 448k ROM.

S0urceror, 2021-08-28:
Wow, you made a great looking PCB.

Unfortunately I stopped supporting FAT32 in the current version of the software. Hardware-wise it still supports it. The main reason was that I wanted to support USB hubs. With an USB hub you can connect multiple USB devices together. Unfortunately you then loose FAT32 support.

But within Nextor you have all the options to mount dsks, partitions, etc. So if you format your USB stick with FAT16, put Nextor.sys and Command2.com on it, it will boot. The rest is looking good! The ROM mapper works.

P.S. I intend to create a boot-menu where you can select FAT16/FAT32 and an upcoming USB Terminal mode.
P.S2. I still need to update the documentation to reflect what I wrote above, sorry for putting you on the wrong path.

denjhang, 2021-08-28:
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
Now I use a 256mb microSD card into the card reader and format it as fat16, and this screen appears. It has been stuck.

denjhang, 2021-08-28:
My USB flash drives are all 32GB, and I cannot format them as fat16.

denjhang, 2021-08-28:
I partitioned my USB flash drives , and then formatted one of the small partitions as fat16, and the result was the same as fat32. msx-usb still cannot recognize the files in the USB flash drive.

denjhang, 2021-08-28:
So currently I hope you can provide software that supports fat32.

denjhang, 2021-08-28:
I found the old version of msx-usb (ver.81356b2ba45cf27de9d9aa865c109b03bfe1bfec), now it can be used normally, I am very excited.

S0urceror, 2021-09-07:
As explained I initially supported FAT32 with separate .DSK image files that could be swapped via the CALL commands (usbfiles, insertdisk, etc.)

Unfortunately the CH376s hardware does not allow combine this with supporting other devices at the same time. Like Ethernet, Keyboard together with an USB stick.

As a result I reverted back to native Nextor support which is FAT16. The CALL commands in the current driver are disabled.

However, I intend to create a super-driver that allows to switch between FAT32, multi-device and terminal mode via hotkeys at the start process. This way we can reinstate this feature for people who want this.

Closed 2021-09-07.

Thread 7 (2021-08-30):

Cannot run sofarun

denjhang, 2021-08-30:
At present, I use the latest version of MSX-USB ROM, and with a 1GB small-capacity USB flash drive, the format is FAT16. I found that this small USB flash drive can be recognized at present. But after entering nextor, I found that it is read-only, and the available space is always about 32MB.

S0urceror, 2021-08-30:
I focused lately on the MSX Terminal extensions for MSX USB. This is great stuff.

With that finished I can investigate your issues more thoroughly. I will document a step-by-step process on my end and put that on the GitHub. Including links to files, etc.

I believe this will help you and others.

In the meantime can you please send me the LSUSB output of your devices? On Linux and Mac lsusb is available on the command line. I made also a similar program for the MSX. This can maybe track why some USB devices are recognized and others not.

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

denjhang, 2021-08-31:
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
After I changed the USB flash drive, the MSX-USB can now correctly identify the capacity and can write files to the USB flash drive. But it seems that sofarun cannot be run at the moment, and a strange error occurs.
In addition, how does emufile simulate multiple disk mirroring? When I use the following command:
emufile a2.dat a2d1.dsk a2d2.dsk a2d3.dsk
emufile set a2.dsk
After MSX restarted, after entering the aleste2 game normally, although the opening animation is normal, but the disk cannot be replaced, I cannot replace the disk with a2d2.dsk, it seems to be a2d1.dsk all the time.

mario-smit-heroes, 2021-09-06:
Please check MSX.org and/or contact the author of Sofarun. Can’t help you with that.

S0urceror, 2021-09-07:
Please check MSX.org and/or contact the author of Sofarun. I am sure they can help you out with the multiple disk issue. I don't play games so much.

Closed 2021-09-07.

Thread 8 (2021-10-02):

Broken link

issalig, 2021-10-02:
In document https://github.com/S0urceror/MSX-USB/blob/59ba23478fe6e7d2f0d7b382198182bf3e068de1/INSTALL.md
there is a link to the images "Here the link to the disk images" , this link points to https://github.com/S0urceror/MSX-USB/raw/master/drivers/flashdrive/dist/dsks.zip but it does not exist.

However the correct link I assume is https://github.com/S0urceror/MSX-USB/blob/master/drivers/archive.zip

S0urceror, 2021-10-02:
No need to work with disk images. That is a left-over from when I did FAT-32 volumes with FAT-16 disk images.

Just format your USB stick with FAT16. That is a bit difficult with modern OS-es but with some command-line you can still do it on Windows 10, MacOS and Linux. Then drop Nextor.sys and Command2.com on it and it should boot.

I saw your post on msx.org but I think you problem is that your particular device is not being recognised. Can you check it's usb class and subclass id with lsusb? It should recognise USB storage class bulk-only devices which are the common one's.

S0urceror, 2021-10-02:
Btw. I want to reintroduce this feature at some point by allowing to choose between fat32, fat16 and multi-device mode or the recently introduced terminal mode. This is coming somewhere later this year.

Closed 2021-10-02.

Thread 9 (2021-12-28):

USB drive support

issalig, 2021-12-28:
I have been able to connect with usb drives with the following values
l usb -v | grep bEndpointAddress

WORK
--
bEndpointAddress 0x01 EP 1 OUT
bEndpointAddress 0x82 EP 2 IN
--
WORK
bEndpointAddress 0x01 EP 1 OUT
bEndpointAddress 0x81 EP 1 IN
--

DOES NOT WORK
bEndpointAddress 0x81 EP 1 IN
bEndpointAddress 0x02 EP 2 OUT

I checked the one that does not work under serial protocol ch376s and it works for parallel I can read the FAT type so I assume hardware is ok and the problem is in the rom.

I have modified the rom and I am printing the communication with ch376s  for working and non working usbs.
However, this is a tedious process (modify code,flash memory with tl866, extract memory, insert into cartridge, power up, test) and I do not still have a solution. How do you do the development? From the video you sent, it looks like you are simulating it, FPGA?

S0urceror, 2021-12-29:
I saw you mentioned this on your GitHub. I haven’t come across this but maybe my endpoints on all 5 or so usb sticks where all the same.

In my setup I have a CH376s module on a breadboard connected to a Teensy. The Teensy is just kind of a relay to the CH376s. Then I have patched OpenMSX to have a virtual MSXUSB cartridge that sends the commands to the Teensy.

This way it behaves like in a real MSX with some timing differences. This enables me to load up everything and also use the OpenMSX debugger. I even rolled my own version of Dezog so that I can step through my assembly code in Visual Studio Code.

Maybe I should make a full write up of this.

PS. I will make a Mac and Windows build of OpenMSX and share it on GitHub this way you can maybe also take the Arduino route and create an emulator.

PS2. While I’m at it I will also check what the endpoint issue is.

Get Outlook for iOS<https://aka.ms/o0ukef>
________________________________
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

issalig, 2021-12-29:
Wow, it is such a great development framework (mine is a poor-man framework: make, gedit, call PRINT and minipro :) ) and yes documenting is a good idea even that is the less interesting part.
So I understand that the teensy is basically and USB to parallel link for the ch376s, neat.

If you like I can send you one of the problematic usbs as well as my pcb version so that you can test it. Just give me an address and you will have it in some days. This is also my way to thank you for the project.

S0urceror, 2021-12-29:
This shows my setup in photo's. On the left the Teensy 3.5 and on the right the Teensy 2.0. These are 5v compatible Arduino type of boards.

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

Would be great to test the problematic devices and solve the issue. This way we solve it for everyone. I am happy to share my address with you but prefer to use email for that. Send me an email to the address found on msx.org and we'll exchange details.

S0urceror, 2021-12-29:
Back to the topic. I have a couple of questions for you:
* Does the not working device say: "-No USB device connected", or is it just not working properly?
* Can you send me the whole lsusb -v dump? Maybe there are more clues there.
* You said: "I think it should be an easier way to bind it to 1. Other projects just set address to 1 0x45 0x01, then select device 1 0x13 0x01 and configuration 1 0x49 0x01". Do you mean dropping Usb Hub support and just using the device connected to the module?

issalig, 2021-12-29:
- Not working means it is not detected. It just says
  -  UNAPI initialised
  -  MSXUSB cartridge found
  -  CH376s version: 3  (also tried with other module version 2 with same results)
  -  And nothing more, it blocks here maybe in an endless loop (just the same in that in the previous image)

- The lsusb output is in https://pastebin.com/rv2srQ7M
- That was a naive/desperated idea given that I do not fully understand the hub scanning, and in the case of 1 usb, just hardwire it, but maybe it has no sense. I just gave some inpiration from https://pulkomandy.github.io/shinra.github.io/albireo.html which connect ch376s to an Amstrad CPC

cristianoag, 2022-02-04:
@issalig , I've been working with @S0urceror and had exactly the same issues you have. With his original code only one USB drive was working ok out of my 12. Then I made a small change on the code just to wait indefinitely for the CH376s interruption. S0urceror was following the specification and waiting 100 cycles for the interruption. I found out that some of the pen drives I have were a lot slower and were making the CH376 generate the interruption just after 1000 cycles. I then changed the code to loop until it gets the interruption and voila... 9 out of the 12 original set are now working ok. The other 3 are not even recognized by the CHS376.

I'm using S0urceror vNext code and changing the ch376_wait_status function. If you want to take a look on the change I made please check https://github.com/cristianoag/MSX-USB/blob/master/drivers/MsxUsbNext/generic/ch376s.c

Hope that helps.

issalig, 2022-02-04:
That's great. I tried MsxusbNext and no device was recognised. Gonna check it asap.

cristianoag, 2022-02-04:
Yes, I had that error as well. Format your USB stick with FAT16, copy a few DSK files and use this version https://github.com/cristianoag/MSX-USB/blob/master/drivers/MsxUsbNext/msx/dist/nextor.rom

It will recognize it and show the files ok.

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

S0urceror, 2022-02-05:
I've just pushed my latest MSXUSBNext updates to GitHub. Followed Cristiano's lead and removed the 100 time try-out counter as well. Beware this can lead to lock-ups when the CH376s decides to not respond at all. Let's test this in practise and see if we keep this or not.

issalig, 2022-02-05:
I tried @S0urceror version which afaik currently is the same as @cristianoag and NOW it works! Well done guys.

With a FAT12  if I select 1.Floppy disk it ends up with a "No enough memory" (which I suppose is correct)
Pressing 2 says "Full disk mode" and everything works.

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

@cristianoag, as I am using a MSX1 with less that 128Kb, I cannot use FAT16 (which is supported by nextor in MSX1)

I am wondering if it could be added some SRAM memory to the board. As far as I know it would only be necessary a chip like HM628512A (for 512k) and some verilog code for the mapper as it is done for the rom, right?. I am a msx noob and I still need to understand this system well. If you can point me to the right direction I will be happy to hear from you.

cristianoag, 2022-02-05:
Format the usb drive with fat16 and save a few dsk files. As you’re using msx1 I believe those need to be 720k in size. I think even with msx1 ch376 will be able to read all files and the code will mount your small dsk files as msx1 disks.

The issue I see now is because the menu is just for 9 files and with msx1 dsks and 4gb you may have hundreds of disks. lol

Time to rethink the menu!

Get Outlook for iOS<https://aka.ms/o0ukef>
________________________________
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

S0urceror, 2022-02-06:
Happy to get this news Issalig!

The floppy option should continue the normal boot sequence and detect the built-in floppy. But if you don’t have one this fails probably. Let me check if we can do this a bit more gracefully.

720KB disk images saved as .DSK files in the root or DSKS folder of the FAT16/32 formatted USB drive should appear as a nice list under options 1. and 2.

I keep updating MSXUSBNext the next couple of weeks so keep an eye out for some updates. The following I want to do:
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
S0urceror, 2022-02-06:
I have updated the menu to have 26 entries A-Z. I will try to get some navigation implemented and include an option to change the disk from Basic. Then you can mount all dsks files you want.

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

issalig, 2022-02-06:
That's great @S0urceror,  I created a FAT16 partitiion with several (4) dsks and it works under MSX1.
@cristianoag at the beginning I did not understand how it worked.

About the delay that for some usbs is long and for others short I was thinking about a calibrarion method, I mean, start with short delay and if it does not work increase it until usb is detected (it can be a maximum of course that will say, no usb detected)
Then store this time as the device response time and use it for all the session.
What do you think?

This weekend I have no free time (I am studying for a Portuguese exam but maybe reading MSX brazilian forums could work both for studying and for procrastinating, nice! )  but in the middle of the week I hope to get some time and study the new msxusbnext developent you've done is the last days and try to see if this calibration idea could work.

S0urceror, 2022-02-06:
Just implemented CALL MOUNTDSK in BASIC. This shows the selection again and allows you to choose another disk image. Disk images are in the root folder or in the DSKS folder of the FAT16/32 formatted USB drive.

issalig, 2022-02-07:
I noticed there the system was super-slow, characters appeared >500ms after the keypress. I am not sure if this is related to the delay introduced here
https://github.com/S0urceror/MSX-USB/blob/master/drivers/MsxUsbNext/generic/ch376s.c#L58

I will look into it with more detail.

issalig, 2022-02-07:
It is both with BASIC and MSDOS when I press a key it take a lot to appear in the screen. IDK, maybe some bad contact in the cartridge slot causes some signal. And yes, I  am almost sure is just related to my machine.

issalig, 2022-02-08:
Got some time and I am trying to compile msxusbnext (under linux) but for some reason when compiling msx folder I find .lk files are not generated.

Makefile dry.run shows this commands but I cannot see any specific to .lk or .ihx
```
$ make -n
sdasz80 -o objs/msxromcrt0.rel msxromcrt0.s
sdcc --verbose -mz80 -c -DNODEBUG -o objs/driver.rel driver.c
sdcc --verbose -mz80 -c -DNODEBUG -o objs/ch376s.rel ../generic/ch376s.c
sdcc --verbose -mz80 -c -DNODEBUG -o objs/hal.rel hal.c
sdcc --verbose -mz80 -c -DNODEBUG -o objs/usbdisk.rel ../generic/usbdisk.c
sdcc -mz80 --code-loc 0x4200 --data-loc 0xc800 --no-std-crt0 -o build/driver.ihx objs/msxromcrt0.rel objs/driver.rel objs/ch376s.rel objs/hal.rel objs/usbdisk.rel
hex2bin -e rom build/driver.ihx
sjasmplus --fullpath --raw=build/chgbnk.bin --sym=build/chgbnk.sym --lst=build/chgbnk.lst chgbnk.asm
sjasmplus --fullpath --raw=build/extra1k.dat --sym=build/extra1k.sym --lst=build/extra1k.lst extra1k.asm
./kernel/mknexrom ./kernel/Nextor-2.1.0.base.dat ./dist/nextor.rom \
						/d:./build/driver.rom /m:./build/chgbnk.bin \
						/e:./build/extra1k.dat
```

The error occurs in the line sdcc -mz80 --code-loc 0x4200 --data-loc 0xc800 --no-std-crt0 -o build/driver.ihx objs/msxromcrt0.rel objs/driver.rel objs/ch376s.rel objs/hal.rel objs/usbdisk.rel
```
sdcc: Generating code...
sdcc: Calling assembler...
sdcc: sdasz80 -plosgffw objs/usbdisk.rel objs/usbdisk.asm
sdcc -mz80 --code-loc 0x4200 --data-loc 0xc800 --no-std-crt0 -o build/driver.ihx objs/msxromcrt0.rel objs/driver.rel objs/ch376s.rel objs/hal.rel objs/usbdisk.rel
at 1: error 4: 'fopen' failed on file 'build/driver.lk'
make: *** [Makefile:43: build/driver.ihx] Error 1

```
Also I had to pass and argument, in my case ```true``` to this line because compiler reports an error.
https://github.com/S0urceror/MSX-USB/blob/2de667e102a2785ea67408f9beaa6fe030070103/drivers/MsxUsbNext/macos/main.c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

cristianoag, 2022-02-08:
You need to create the build folders. I already ported the makefiles and everything needed to Linux. Also did the changes to makefiles to use gcc, etc. check my GitHub.

Get Outlook for iOS<https://aka.ms/o0ukef>
________________________________
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

issalig, 2022-02-08:
Yes, I had the build folder, but the problem is I am able to compile the linux folder but not the msx folder.
Can you try rm obj/* and make from the msx folder?

cristianoag, 2022-02-08:
Mine work just fine. I also changed the makefile to clean everything appropriately.

Get Outlook for iOS<https://aka.ms/o0ukef>
________________________________
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

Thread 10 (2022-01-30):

CH376S v2 and v3 stability

cristianoag, 2022-01-30:
I built one of the MSX-USB boards, programmed the ATF1504AS and the SST39SF040 (with nextor.rom found here in the repo). Initially I built the board with a CH376S v2 and noticed it was super unstable. Sometimes it was detecting the USB stick ok and loading MSX-DOS, sometimes it was just saying "USB not detected". Sometimes it was loading the MSX-DOS but after some time disk operations couldn't be executed anymore with a disk error. Super strange.

Troubleshooting I replaced the ATF1504AS by another one, same behavior. Replaced the SST39SF040 by another one, same errors. Then I decided to solder a female pin header and experiment with multiple CH376S versions. I noticed that with v3 it is a lot more stable. I managed to even load a game from the USB, but still had some issues (less frequent tough).

For example right now with V3 I executed a dir just ok. Went here to write this and when I came back, when executing dir again I just got no files on the disk. 0 bytes in 1 file! :/

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

Is it something you also observe? Am I missing something? Any tips?

cristianoag, 2022-01-31:
More time investigating. I flashed the nextor.rom image available here https://github.com/issalig/MSX-USB/blob/master/drivers/NextorUsbHost/dist/nextor.rom and that one seems a more stable. Now I can use CH276S v2 or v3. Errors are still happening, but it seems that old version works better with v2.

S0urceror, 2022-01-31:
Hi Cristiano,

v3 is indeed a bit more stable then v2. I recently did some test together with Issalig and fixed a couple of things. Could be he has that version on his Github. I have attached this version (NEXTOR.ROM) to this email as well.

Let me know how this goes.

P.S. I am also working on a completely different driver (MSXUSBNext) that only supports USB drives not other USB devices. This thing allows you to choose a .DSK image from a FAT16 or FAT32 formatted USB. I have also included that version here.

Regards,

Mario

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

cristianoag, 2022-01-31:
Great if we can have a version dedicated to storage and another focused on extensibility. I haven't received any file attached... I think github stripes files out when sending e-mails. Can you send to cristianoag@hotmail.com instead?

If you can also explain how you're connecting the CH376S to OpenMSX we can actually help you with the code. I'm planning to use a Linux running on the raspberry pi so I can connect the CH376 to its pin headers. Is that the approach you're using? I'll have to recompile OpenMSX to adapt that approach tough.

S0urceror, 2022-01-31:
Hi Cristiano,

My setup looks like this:

  *   Dezog<https://github.com/S0urceror/DeZog.git> debugger in VSCode connecting to OpenMSX.
  *   OpenMSX with a virtual MSXUSB device. I have the code here<https://github.com/S0urceror/openMSX.git> which should compile on Linux.
  *   This virtual device converts the IN and OUTs of the Z80 to serial commands to an Arduino powered 5v compatible Teensy.
  *   The Arduino code you can find on my Github<https://github.com/S0urceror/MSX-USB/raw/master/hardware/arduino/noobtocol.parallel/noobtocol.parallel.ino> as well. I have different flavours so you can wire the CH376s board in SPI or in Parallel mode.
  *   The Arduino code converts the serial commands to CH376s commands.

For the MSX in openMSX it looks like it is talking to the real device with the same response. Only timing is different than on the physical hardware. Sometimes that is were the problems come from. But most of the times it is devices that are not behaving as the standard says.

Regards,

Mario

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

cristianoag, 2022-01-31:
Amazing. I will work asap to setup my dev environment. Looking into your code I see those stability issues may be caused by the way you are doing time synchronization on your code. I see you have routines to wait across the code and I think the recommended approach would be hooking something to the timer interrupt routine (DRV_TIMI:) instead. I agree it is a much more complex code, but to have MSX-USB rock solid we may need to attack that front as well.

S0urceror, 2022-01-31:
I do waits by counting down a number of HALTs. When interrupts are enabled this should give an approximation of 1/50th or 1/60th of a second. I made sure to be a bit on the upper end of the needed wait. This is not so critical. Unless you have a drive that needs a lot more time to respond.

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

cristianoag, 2022-01-31:
Lol. Only my oldest thumb drive actually works with msxusb. And I have more than 20 laying around here. Only one works ok. I would say it it is pretty old.

Get Outlook for iOS<https://aka.ms/o0ukef>
________________________________
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

cristianoag, 2022-01-31:
Well. Not mixing this issue with the other one reported by issalig on the flash drives not supported. The only one that actually work for me has the following output from lsusb:

Bus 001 Device 006: ID 058f:6387 Alcor Micro Corp. Flash Drive
Couldn't open device, some information will be missing
Device Descriptor:
  bLength                18
  bDescriptorType         1
  bcdUSB               2.00
  bDeviceClass            0
  bDeviceSubClass         0
  bDeviceProtocol         0
  bMaxPacketSize0        64
  idVendor           0x058f Alcor Micro Corp.
  idProduct          0x6387 Flash Drive
  bcdDevice            1.03
  iManufacturer           1 Generic
  iProduct                2 Mass Storage
  iSerial                 3 DCA6127E
  bNumConfigurations      1
  Configuration Descriptor:
    bLength                 9
    bDescriptorType         2
    wTotalLength       0x0020
    bNumInterfaces          1
    bConfigurationValue     1
    iConfiguration          0
    bmAttributes         0x80
      (Bus Powered)
    MaxPower              200mA
    Interface Descriptor:
      bLength                 9
      bDescriptorType         4
      bInterfaceNumber        0
      bAlternateSetting       0
      bNumEndpoints           2
      bInterfaceClass         8 Mass Storage
      bInterfaceSubClass      6 SCSI
      bInterfaceProtocol     80 Bulk-Only
      iInterface              0
      Endpoint Descriptor:
        bLength                 7
        bDescriptorType         5
        bEndpointAddress     0x01  EP 1 OUT
        bmAttributes            2
          Transfer Type            Bulk
          Synch Type               None
          Usage Type               Data
        wMaxPacketSize     0x0200  1x 512 bytes
        bInterval               0
      Endpoint Descriptor:
        bLength                 7
        bDescriptorType         5
        bEndpointAddress     0x82  EP 2 IN
        bmAttributes            2
          Transfer Type            Bulk
          Synch Type               None
          Usage Type               Data
        wMaxPacketSize     0x0200  1x 512 bytes
        bInterval               0

It is funny that I have other one that has exactly the same parameters. Both work on Linux and Windows, but just one work with MSXUSB.

cristianoag, 2022-01-31:
Here is the thing. Did a collection of all USB thumb drives from all members of my family. Got another one that work flawlessly. I think the issue is in fact with the other one I have that kind of work, but not 100% compatible. Let's close this one and stop spending time with this. The issue is only that there are so few types that actually work ok.

cristianoag, 2022-02-01:
Still facing the issue. It is just less frequent with the new flash drive.

Closed 2022-02-06.

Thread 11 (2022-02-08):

Installation adventures.

issalig, 2022-02-08:
I create this not to mix comments with other stuff.

issalig, 2022-02-08:
@crsitianoag It asks for a repository
```
$ sudo apt-get build-dep openmsx
Leyendo lista de paquetes... Hecho
E: Debe poner algún URI «deb-src» en su «sources.list»
```

cristianoag, 2022-02-08:
openmsx.org/manual/compile.html

Get Outlook for iOS<https://aka.ms/o0ukef>
________________________________
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

issalig, 2022-02-08:
Well, I finally compiled S0urceror's OpenMSX , in my system I needed ```sudo apt-get install tcl-dev``` not ```libtclcl1-dev```
I still have to setup download machine roms and more config stuff, but this will be tomorrow.
Thanks @cristianoag for your help.

issalig, 2022-02-09:
Finally, I have everything working.
I started a document not to loose all the steps https://github.com/issalig/MSX-USB/blob/master/installation.md
It is still work in progress.

issalig, 2022-02-09:
I found a bug while I was checking my ch376s with https://github.com/S0urceror/MSX-USB/blob/master/test/usb_via_arduino/src/main.parallel.cpp

main_paralell  crashed when printing iProd due to a small buffer https://github.com/S0urceror/MSX-USB/blob/2de667e102a2785ea67408f9beaa6fe030070103/test/usb_via_arduino/src/main.parallel.cpp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

In get_string2 https://github.com/S0urceror/MSX-USB/blob/2de667e102a2785ea67408f9beaa6fe030070103/test/usb_via_arduino/src/main.parallel.cpp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 data has size max_packet_size which is 64

But then in
https://github.com/S0urceror/MSX-USB/blob/master/test/usb_via_arduino/src/main.parallel.cpp#L799
length is 255  and when being bzeroed it corrupts memory.

I fixed it by changing https://github.com/S0urceror/MSX-USB/blob/2de667e102a2785ea67408f9beaa6fe030070103/test/usb_via_arduino/src/main.parallel.cpp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 to uint8_t* data=(uint8_t*) malloc (255)

Tell me if you are experiencing the same.

cristianoag, 2022-02-09:
I believe that bus just a test program. You should focus on the drivers folder.

Get Outlook for iOS<https://aka.ms/o0ukef>
________________________________
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

S0urceror, 2022-02-09:
> I found a bug while I was checking my ch376s with https://github.com/S0urceror/MSX-USB/blob/master/test/usb_via_arduino/src/main.parallel.cpp

Good catch. Never happened here because the USB strings are usually not so long. I have now changed the setup package to request maximum 64 bytes as well.

And pushed the change back to GitHub.

S0urceror, 2022-02-09:
> Finally, I have everything working.
> I started a document not to loose all the steps https://github.com/issalig/MSX-USB/blob/master/installation.md
> It is still work in progress.

Nice write up. Would you be okay to merge all your updated instructions with the main once you consider them finished?

issalig, 2022-02-09:
Yes of course, that's the idea. I will tell you when It is finished. Also i wrote info about programming the cpld and the flash so everything is documented.

S0urceror, 2022-02-10:
Hi Issalig,

You can indeed safely remove this. Initially I retrieved the serial attributes, modified only the ones that need changing, and set them. Now that we have bzero afterwards all gets reset. No need to first retrieve the attributes.

Regards,

Mario

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

issalig, 2022-03-23:
I just write here as a reminder to change instructions (mainly paths and few other things) to make it work with recent @cristianoag  linux support.

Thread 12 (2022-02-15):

msxusb next 0.3 don´t stop to select option

pakoto, 2022-02-15:
Old version stop on boot, prompt to select "1 - 2" option. After flash 0.3 version, boot directly to alphabet dsk selection. Only if push 1 or 2 quickly during boot, can do it.

S0urceror, 2022-02-15:
I am planning to incorporate a feature that boots the last selected DSK unless you press another key. Is that what you are looking for?

pakoto, 2022-02-15:
Ah, ok. You intentionally look for a start without pauses. Old version stop until you select an option.

S0urceror, 2022-02-19:
Hi Pakoto, please check the version I just uploaded here: https://github.com/S0urceror/MSX-USB/tree/master/drivers/MsxUsbNext.

pakoto, 2022-02-20:
thanks! 1 - 2 menu returns... but if you push esc two or more times, skip it. Could you modify ESC key to "do nothing" into boot menu?

pakoto, 2022-02-20:
https://youtu.be/I2ts-EqIGf4?t=52

I think push ESC = push ´1´

S0urceror, 2022-02-20:
Can you please tell me a bit more about your MSX? MSX 1, 2, 2+ or TurboR? What language/keyboard layout?

What the menu does is print:
MSXUSB-NXT v0.3 (c)Sourceror

Select device:
1.FLOPPY       2.USBDRIVE

Or, select DSK image [/]:
A.\80s         B.AUTOEXEC.DSK C.\dsks        D.\mm          E.\msxusb
F.\music       G.\network     H.\nextor      I.\roms        J.\saves
K.\settings    L.\sofarun     M.\tmp         N.\tools       O.\unapi
P.\vgmplay
And then it waits for your keypress.

Press keys 1 or 2 to select the built-in floppy or the whole USB device as the drive (FAT12 and FAT16) only.
Press keys A to Z to select a DSK image or a subfolder on the disk.

With an AUTOEXEC.DSK file in the root it will wait 3 seconds and countdown. If you press nothing it will load AUTOEXEC.DSK. If you press ESC it will show the menu above.

Please carefully explain to me what is not working as explained above and I’ll try to help/fix it.

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

S0urceror, 2022-02-20:
Sorry didn’t notice you included a video. Thanks for this.

It is a FS4000 MSX1.

I see you have a AUTOEXEC.DSK on the drive and that you press ESC so that it does not boot automatically. I see that you try to boot the whole USB device ‘2’ and that works. Booting floppy ‘1’ results in a Memory Error because there is not built-in floppy in your MSX. Does selection ‘A’ to ‘Z’ do anything?

I’ll check in the openMSX emulator to see how it behaves.

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

pakoto, 2022-02-20:
Please check video. Don't worry about memory error. I test msx1 with and without ram mapper in this video

When you push "esc" key more that one time, boot with 1 option.

Msx1 national fs4000 jap

https://youtu.be/i9LXwF0oVuU

S0urceror, 2022-02-20:
Ah yes, pushing any button other then 1, 2 or A to Z will automatically select floppy. I’ll update my next version so that pushing ESC more than 1 time will not do anything.

Thx.

Btw, great machine you have, built-in printer, word processor. We never had these here in Europe.

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

S0urceror, 2022-02-20:
Fixed it in v0.4. It’s in my GitHub.

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

pakoto, 2022-02-20:
Solved. Thanks again!

Closed 2022-02-21.

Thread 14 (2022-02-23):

UsbKeyboard driver not recognizing keyboards

cristianoag, 2022-02-23:
Opening this one so we can invest time to discover the reason the UsbKeyboard driver is not recognizing keyboards that it is supposed to support.

issalig, 2022-02-23:
A friend of mine also reported he is not able to make it work (I have not tried yet) . I will ask kim for details.

@cristianoag, I am working in the flash tool because it does not work for 39sf040 because it has different operation bytecodes.  Maybe you are also interesed in the discussion. You can see it at https://github.com/S0urceror/MSX-USB/issues/1

S0urceror, 2022-03-13:
Cristiano, Issalig, please check the MSXUSB version I just checked in.

I fixed an issue in the USB STALL mechanism. When a device is not ready it STALLs and then the driver just has to retry after clearing the STALL situation. Somehow the CH376s does not report the status of this correctly and the driver thought it was failing. As a result the keyboard (and other devices) where not recognised at start.

You should see a message at MSX start saying:
+ x device(s) connected
+ No USB storage

Where x is bigger or equal to 1, depending if you run behind an USB Hub.

issalig, 2022-03-15:
Nice, it is good to see some progress here!

I am testing in a real VG8020  MSX1 with a usb hub, a usb drive formatted as 720kb and a keyboard and the new version of MSXUsbHost (nextor.rom)

I get correctly the 3 devices (Hub, usb drive and keyboard but I had to capture video and pause it, because this message appears just some ms, maybe a 1s delay would be nice
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
)

Then tried usbkeybd.com  but it gets an error.

Is this the right way of using it?

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

cristianoag, 2022-03-15:
Just run usbkeyb not usbkeyb.com

Get Outlook for iOS<https://aka.ms/o0ukef>
________________________________
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

issalig, 2022-03-15:
Now it loads but nothing happens, I mean when I press keys in the keyboard nothing appears. (I use a logitech k120 usb keyboard)
Also I noticed caps/numeric leds do not work.

@cristianoag  did you manage to make it work?

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

cristianoag, 2022-03-15:
I haven’t tested after the latest changes. Planning to do that this week.

Get Outlook for iOS<https://aka.ms/o0ukef>
________________________________
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

S0urceror, 2022-03-15:
You should see a couple of messages appearing after running usbkeybd.com and the UNAPI driver should be running. Don’t know how this works on an MSX1 so that might explain what you see. I’ll test this later tonight.

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

cristianoag, 2022-03-21:
I tested earlier today with real hardware (both MSX1 and MSX2). It is not working. On MSX2, it is not recognizing any of the USB hubs I have (I tested 4, powered and not powered), with the previous version it does say I have multiple USB devices connected but doesn't differentiate the hub from the USB storage device that contains MSX DOS and the utilities I need to load the driver. With my MSX1 is even worse, it starts the boot sequence and after a few seconds says "out of memory".

Another strange symptom is that sometimes with MSX2, it starts the boot sequence and then just restart the computer after a few seconds.

I believe this new version is worse than the previous @***@***.***>. How did you test? Only with the OpenMSX or with real hardware?

Cristiano

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

S0urceror, 2022-03-21:
I tested this with OpenMSX and the test board. I think you are right I should have done extensive testing on real hardware before calling it fixed. I’ll try to reserve some time for this later this week and let you know.

Email written on my mobile device
________________________________
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

cristianoag, 2023-01-13:
We can close this one. Keyboard need to follow the specifications to be recognized ok. I got a few already working.

issalig, 2023-01-25:
Can you post the keyboard models that work?

Closed 2023-01-13.

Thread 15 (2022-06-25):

Latest build is not working with folders

cristianoag, 2022-06-25:
@S0urceror - The latest MSXUSB build is not working well with folders. You enter folders, they are shown on the path but when you execute dir it is getting back to the root of the disk. I think there is an issue on the code.

S0urceror, 2022-06-27:
I assume MSXUSB and not MSXUSBNext. In MSXUSB you mount an USB stick as a whole drive and Nextor takes care of the file and folder management. As long as it's FAT12 or FAT16 this should work fine.

To be exact you use the CD <folder> and DIR commands?

Can you confirm?

cristianoag, 2022-06-29:
Fixed. The changes were submitted in a pull request. I tested on openMSX and real hardware. Working in both.

cristianoag, 2022-06-30:
Temp solution was submitter, but it seems we have a bug identifying changes on the disk.

S0urceror, 2022-08-19:
Hi Christiano, sorry for the long wait. Had some construction going on in my house followed by a nice holiday. I just checked your comments and your code recommendations. I found out that I never initialised workarea->disk_change. Now it does. In normal use it will now always return 1. Only when you use the CALL MOUNTDSK command in Basic to load another image it does only one time return 2 to indicate the change to Nextor and subsequently again 1's. This solves the issue (I hope). Can you test the latest update?

S0urceror, 2022-08-21:
Looks like yesterday's version was build with SDCC 4.2.0 and that does (currently) not work. Anyway, I rebuild and pushed the latest version again to GitHub.

Did some tests and I confirm it is working as promised:
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

S0urceror, 2022-09-01:
Closing this issue now since I believe it's fixed in the last release.

Closed 2022-09-01.

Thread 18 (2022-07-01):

USBNEXT does not load some programs on mounted .dsk

issalig, 2022-07-01:
Test equipment: VG8020 (MSX1)

Mounting a .dsk , for example https://drive.google.com/file/d/1uAYQdP8-Zte_G4u_4CSZ_ULAv0S5TIIP/view?usp=sharing

For example, it loads execrom.com but it does not load bombj.com

Any hint?

cristianoag, 2022-07-01:
It is running ok on my MSX2. I know you're testing on MSX1 Issalig, I need to get mine from its box to test and that will take some time. Meanwhile, can you test with this ROM https://github.com/cristianoag/MSX-USB/blob/master/drivers/MsxUsbNext/msx/dist/nextor.rom ?

Cristiano

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

cristianoag, 2022-07-01:
Try only bombj (without the com). You see, there weren’t any read operations. The OS reported the error without even touch the disk.

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

cristianoag, 2022-07-01:
How have you created BOMBJ.COM?

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

issalig, 2022-07-01:
No, it is a game you can find in this dsk
 https://drive.google.com/file/d/1uAYQdP8-Zte_G4u_4CSZ_ULAv0S5TIIP/view?usp=sharing

cristianoag, 2022-07-01:
Uhm. Yeah… something is wrong.

I asked how you created bombj.com because originally that game is found as a rom file. Some software transformed the rom file into a com file. I just wanted to know which software to better understand what is going on.

But I found other bugs in the next code that need review as well. Those may be related.

The bug I found is related to how the driver detects if the disk changed. But that information is coming from an assembler routine that I didn’t understand well. Sourceror needs to check as he wrote that part.

Get Outlook for iOS<https://aka.ms/o0ukef>
________________________________
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

issalig, 2022-07-02:
Do not exactly what it does, but pretty sure it was converted and probably uses dirty tricks. But in MsxUsbHost it works nice.

cristianoag, 2022-07-09:
@issalig, can you please drop me a message on cristianoag@hotmail.com?

S0urceror, 2022-08-19:
Hi Issalig, I just fixed a bug that Cristiano pointed out earlier. I'll do some further testing and also check that with Bomberjack. I'll let you know the result later.

S0urceror, 2022-08-21:
On MSX2 it works fine.

On MSX1 in a debug build it shows this:
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

I noticed on MSX2 it loads much more sectors, like this:
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

Then resets and starts the game.

S0urceror, 2022-08-21:
Also tried the old MSXUSB (not Next) and got the same result:
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

S0urceror, 2022-08-21:
You are right that the old MSXUSB loads it. Previous test was wrong:
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

Also tried another .ROM file from FileHunter and tried loading with EXECROM. Also doesn't work. Interesting... More research is needed.

issalig, 2022-08-22:
Next week I will get a sony  hb20p . I will check It there too but i Guess It Will behave similar to vg8020

S0urceror, 2022-08-31:
Hi issalig,

Spend a bit more time research MSXUSBNext:

- MSX1 vs MSX2 does not matter.
- Memory mapper vs normal 64KB does not matter.
- Having a DOS1 diskrom present in the system => both MSX1 and 2 work.

I tested your VG8020 in OpenMSX. UsbNext with BOMBJ does not work. Once you load a Philips Floppy interface and reset then UsbNext with BOMJ works! Remove it again, reset, and it doesn't work anymore.

So, it looks like a DISKROM must be present to be able to run BOMBJ.com. On MSX2 this is already built-in. On MSX1 this is usually added via a cartridge.

Still, why does the old MSXUSB not have this requirement? The search is not yet over...

S0urceror, 2022-09-11:
Ok, found it. It looks like this is a very special case in Nextor that causes this. I fixed it and asked it to be included in a next release.

The new release file [nextor.rom](https://github.com/S0urceror/MSX-USB/blob/master/drivers/MsxUsbNext/msx/dist/nextor.rom) in the dist folder is already patched and BOMBJ.COM is working!

S0urceror, 2022-09-13:
Great. Happy to hear it’s working. This was a tough one to find.

Email written on my mobile device
________________________________
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

Closed 2022-09-11.

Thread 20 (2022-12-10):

alternative aliexpress CH376 usb module support

pakoto, 2022-12-10:
**Is your feature request related to a problem? Please describe.**
no

**Describe the solution you'd like**
alternative aliexpress CH376 usb module support

**Describe alternatives you've considered**
ch376 usb modules ordered from aliexpress, and receive different version with incompatible pinout (?). Picture attached.
Could it work with a different version of pcb?

**Additional context**
Add any other context or screenshots about the feature request here.
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

S0urceror, 2022-12-11:
Looks quite similar to the ones I use. Only difference is the jumper. What are the markings on this? You should set it to P or Parallel because that is how the MSXUSB cartridge communicates with it.

S0urceror, 2022-12-11:
I see also that the connector pinout is completely different. Viewed from the top with the connector below you would have first D0 to D7 on the PCB edge with WR,RD,CS,A0,INT,VCC and GND on the PCB inside. Also the order is different.

You can still wire it up with Dupont jumper cables and see if they work but that is not a compact solution to fit in a cartridge case.

S0urceror, 2022-12-11:
It looks like you have to create an updated MSXUSB PCB to match this pinout.

cristianoag, 2023-01-13:
I got one of those boards as well and will create a version that supports that version of the CHS. I'll create a pull request in the future with the new board.

issalig, 2023-01-25:
I am working on that modification. @cristianoag , I will let you know about my progress.

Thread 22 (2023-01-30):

sofarom load megarom games from usb while execute

pakoto, 2023-01-30:
I don´t know if it is msxusb bug or sofarom bug.
Video here.

https://youtu.be/IYN5BVrKvnI

S0urceror, 2023-01-31:
Interesting, looks like it continuous to load within the game. I am interested to find out what happens. I'll investigate and let you know.

zomgugoff, 2024-08-02:
I noticed this also with Space Manbow. The game will hang and graphics corrupt while it loads mid-gameplay

S0urceror, 2024-08-18:
Is it possible to use the /X flag in SofaRom or Disable Disk Driver in SofaRun?

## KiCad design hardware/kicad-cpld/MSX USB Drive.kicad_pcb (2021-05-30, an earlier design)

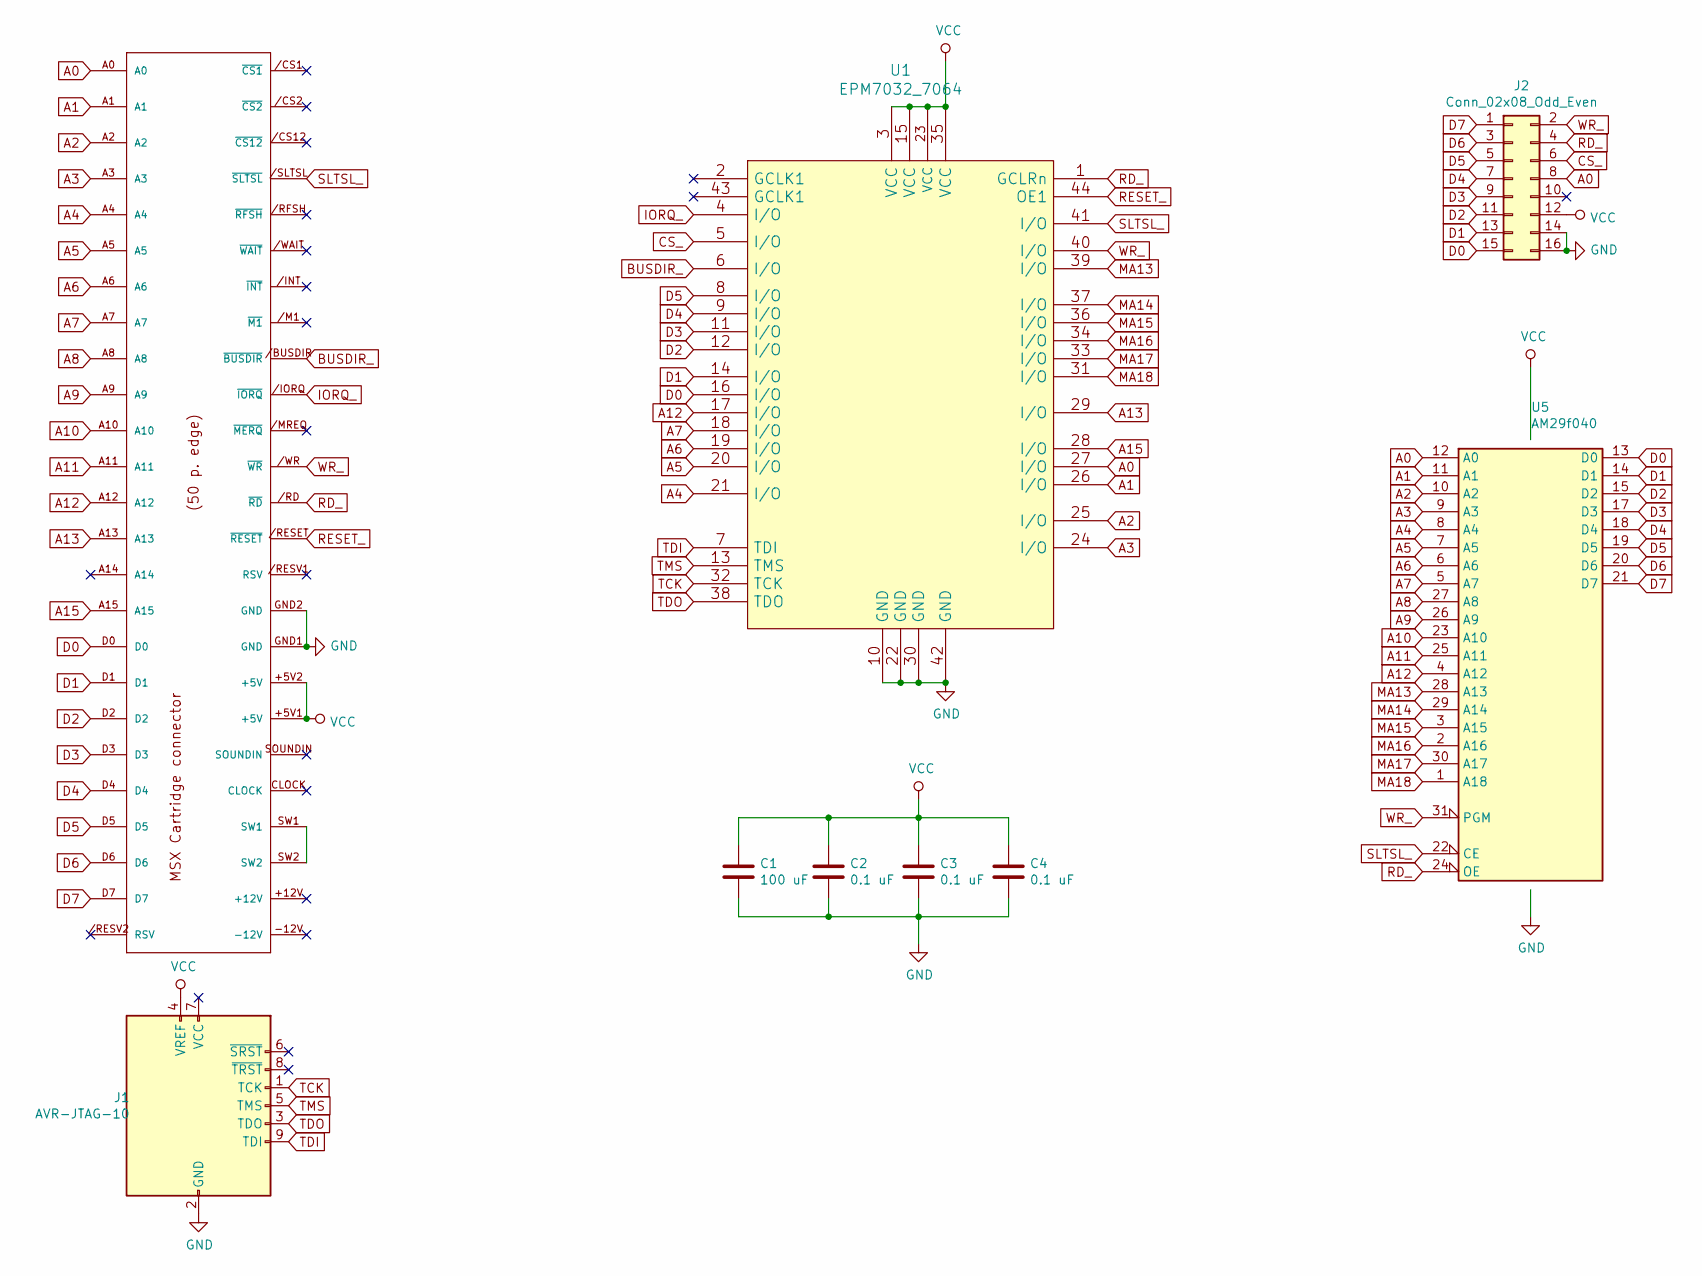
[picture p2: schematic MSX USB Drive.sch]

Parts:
C1: 100 uF; CP_Elec_6.3x5.4
C2, C3, C4: 0.1 uF; C_0805_2012Metric_Pad1.15x1.40mm_HandSolder
EDG1: MSX_CON; msx-con-MSXCART
J1: AVR-JTAG-10; PinHeader_2x05_P2.54mm_Vertical
J2: Conn_02x08_Odd_Even; PinHeader_2x08_P2.54mm_Vertical
U1: EPM7032_7064; PLCC44
U5: AM29f040; DIP-32_W15.24mm_Socket

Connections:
A0: EDG1.A0, J2.8, U1.27 (I/O), U5.12 (A0)
A1: EDG1.A1, U1.26 (I/O), U5.11 (A1)
A2: EDG1.A2, U1.25 (I/O), U5.10 (A2)
A3: EDG1.A3, U1.24 (I/O), U5.9 (A3)
A4: EDG1.A4, U1.21 (I/O), U5.8 (A4)
A5: EDG1.A5, U1.20 (I/O), U5.7 (A5)
A6: EDG1.A6, U1.19 (I/O), U5.6 (A6)
A7: EDG1.A7, U1.18 (I/O), U5.5 (A7)
A8: EDG1.A8, U5.27 (A8)
A9: EDG1.A9, U5.26 (A9)
A10: EDG1.A10, U5.23 (A10)
A11: EDG1.A11, U5.25 (A11)
A12: EDG1.A12, U1.17 (I/O), U5.4 (A12)
A13: EDG1.A13, U1.29 (I/O)
A15: EDG1.A15, U1.28 (I/O)
BUSDIR_: EDG1./BUSDIR (~BUSDIR), U1.6 (I/O)
CS_: J2.6, U1.5 (I/O)
D0: EDG1.D0, J2.15, U1.16 (I/O), U5.13 (D0)
D1: EDG1.D1, J2.13, U1.14 (I/O), U5.14 (D1)
D2: EDG1.D2, J2.11, U1.12 (I/O), U5.15 (D2)
D3: EDG1.D3, J2.9, U1.11 (I/O), U5.17 (D3)
D4: EDG1.D4, J2.7, U1.9 (I/O), U5.18 (D4)
D5: EDG1.D5, J2.5, U1.8 (I/O), U5.19 (D5)
D6: EDG1.D6, J2.3, U5.20 (D6)
D7: EDG1.D7, J2.1, U5.21 (D7)
GND: C1.2, C2.2, C3.2, C4.2, EDG1.GND1 (GND), EDG1.GND2 (GND), J1.2 (GND), J1.10 (GND), J2.14, J2.16, U1.10 (GND), U1.22 (GND), U1.30 (GND), U1.42 (GND), U5.16 (GND)
IORQ_: EDG1./IORQ (~IORQ), U1.4 (I/O)
MA13: U1.39 (I/O), U5.28 (A13)
MA14: U1.37 (I/O), U5.29 (A14)
MA15: U1.36 (I/O), U5.3 (A15)
MA16: U1.34 (I/O), U5.2 (A16)
MA17: U1.33 (I/O), U5.30 (A17)
MA18: U1.31 (I/O), U5.1 (A18)
unnamed: EDG1.SW1, EDG1.SW2
RD_: EDG1./RD (~RD), J2.4, U1.1 (GCLRn), U5.24 (OE)
RESET_: EDG1./RESET (~RESET), U1.44 (OE1)
SLTSL_: EDG1./SLTSL (~SLTSL), U1.41 (I/O), U5.22 (CE)
TCK: J1.1 (TCK), U1.32 (TCK)
TDI: J1.9 (TDI), U1.7 (TDI)
TDO: J1.3 (TDO), U1.38 (TDO)
TMS: J1.5 (TMS), U1.13 (TMS)
VCC: C1.1, C2.1, C3.1, C4.1, EDG1.+5V1 (+5V), EDG1.+5V2 (+5V), J1.4 (VREF), J2.12, U1.3 (VCC), U1.15 (VCC), U1.23 (VCC), U1.35 (VCC), U5.32 (VCC)
WR_: EDG1./WR (~WR), J2.2, U1.40 (I/O), U5.31 (PGM)

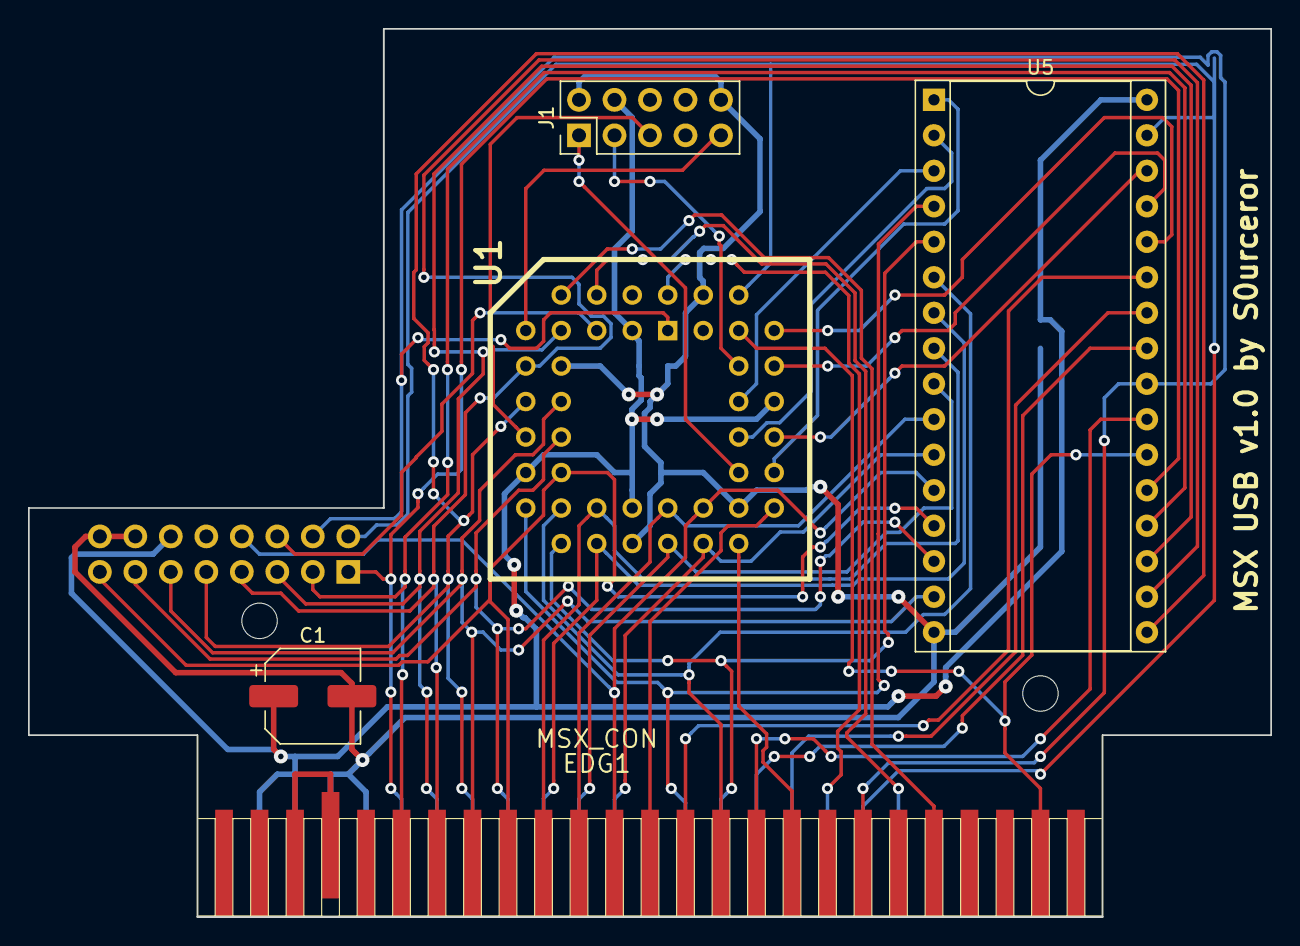
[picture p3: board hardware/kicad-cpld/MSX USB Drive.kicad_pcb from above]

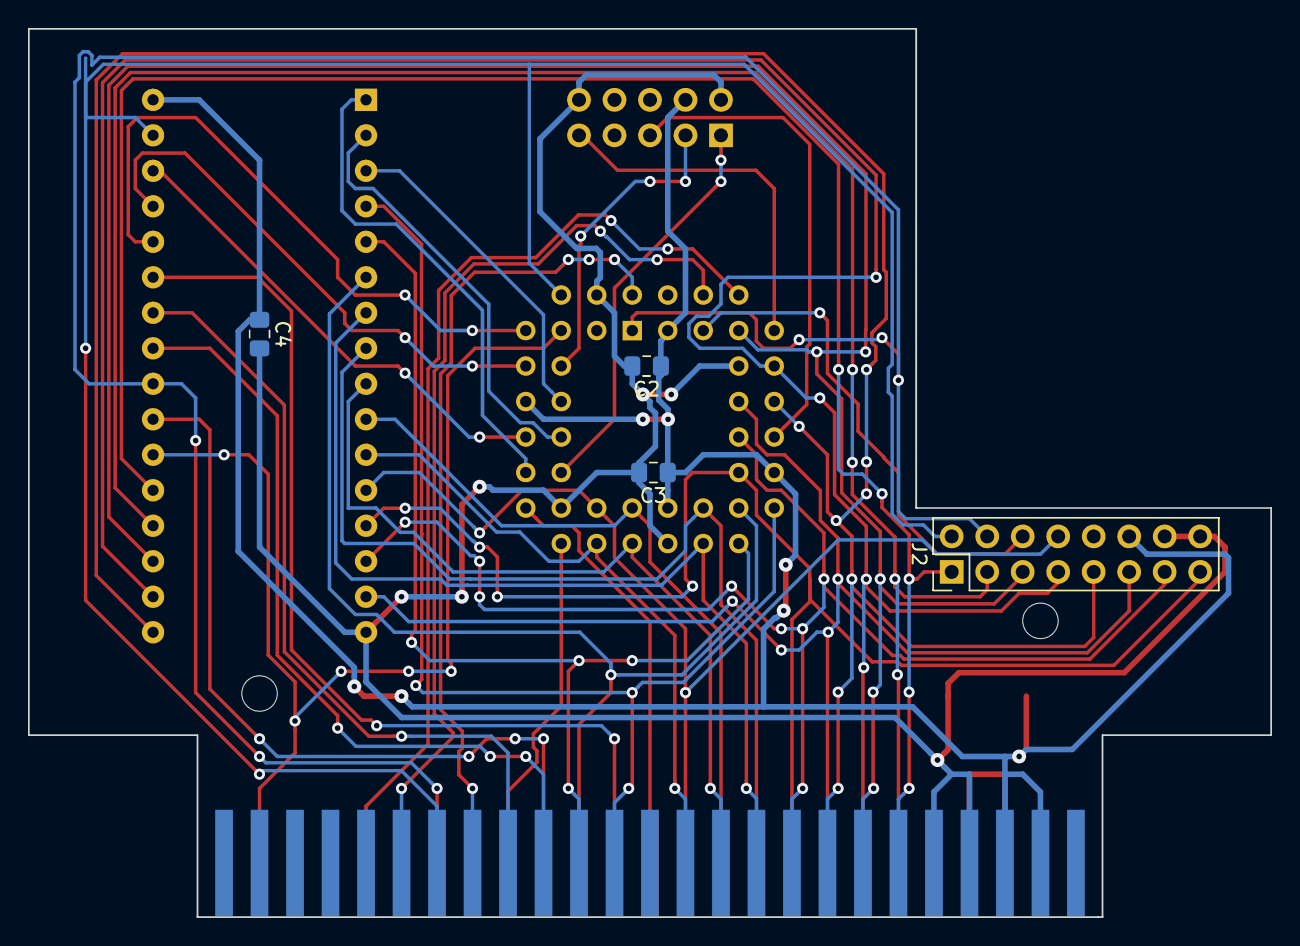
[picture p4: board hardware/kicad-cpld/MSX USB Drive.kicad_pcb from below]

Board: 2 copper layers, 88.9 x 63.6 mm, 9 parts (4 on the bottom side), 43 nets.

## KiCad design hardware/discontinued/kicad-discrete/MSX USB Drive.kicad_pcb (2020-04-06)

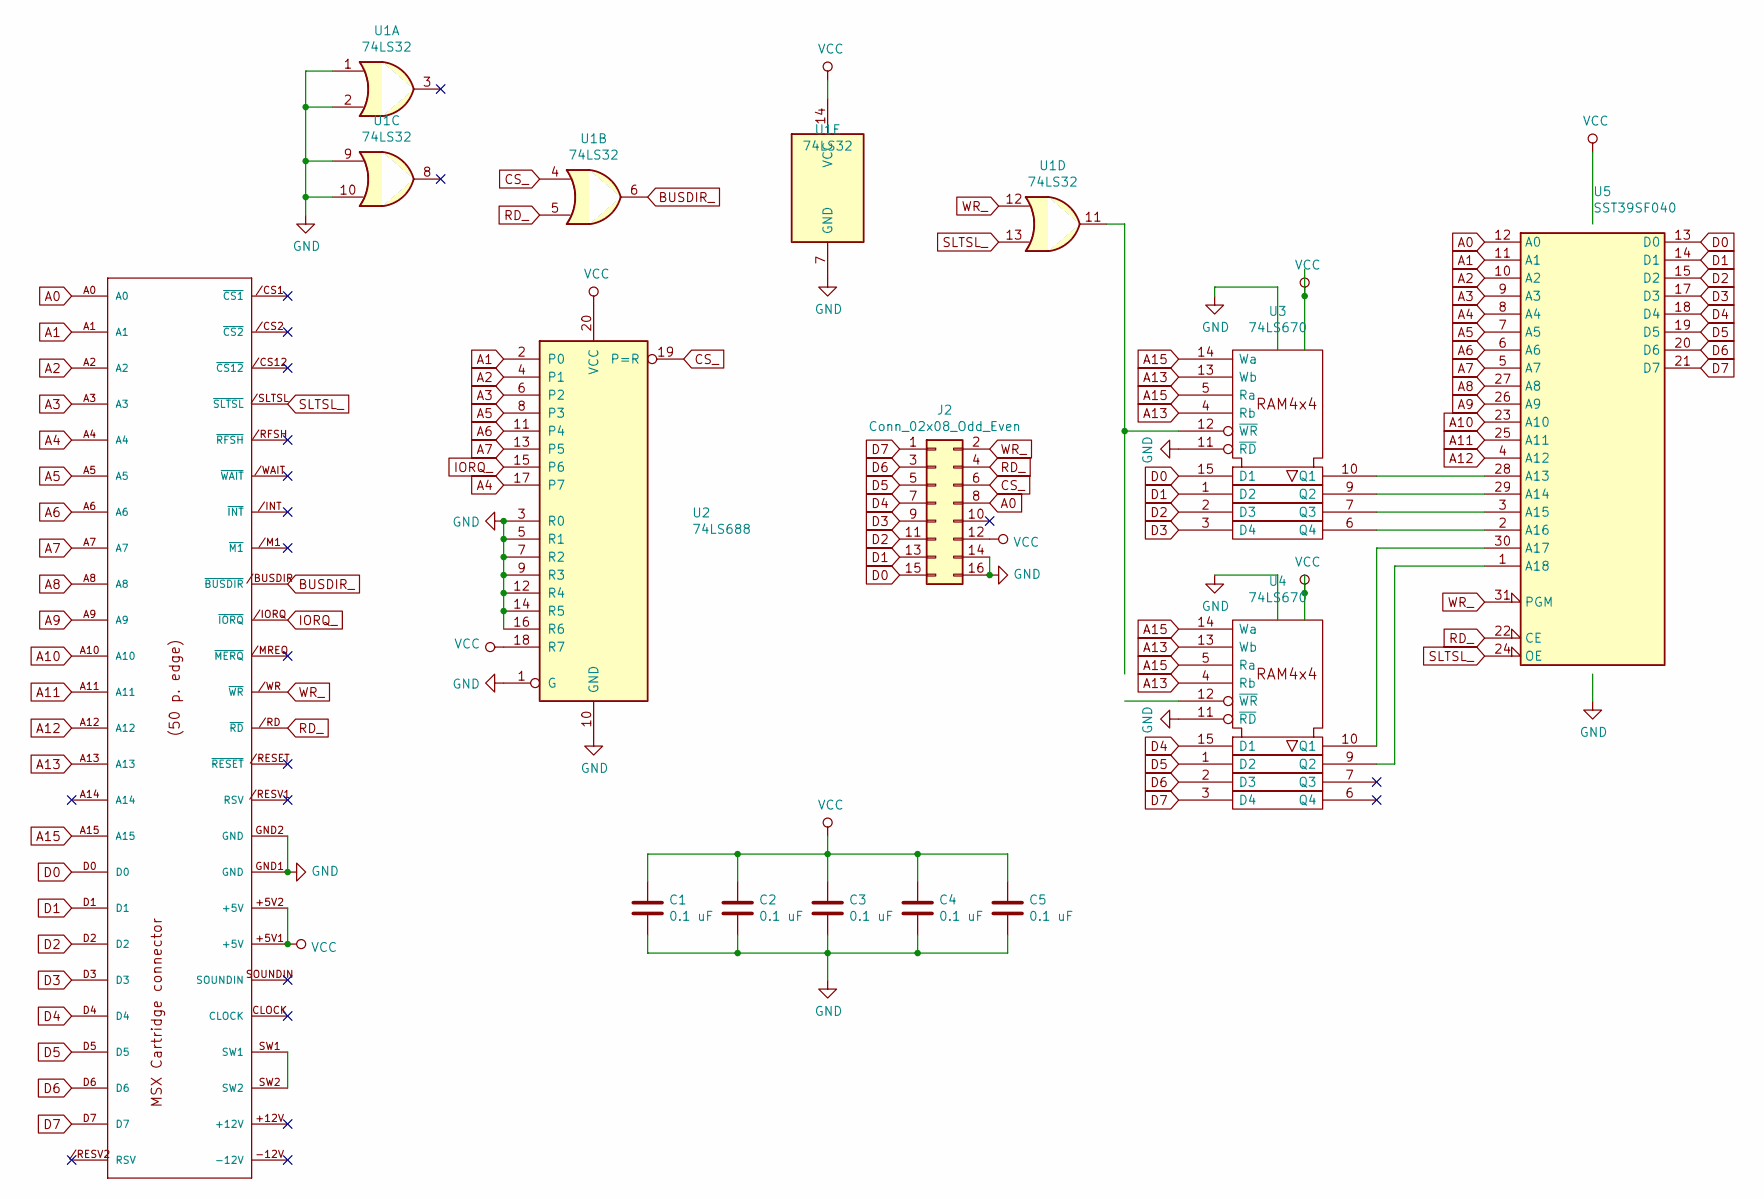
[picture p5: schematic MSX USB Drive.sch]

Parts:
C1, C2, C3, C4, C5: 0.1 uF; C_Radial_D6.3mm_H5.0mm_P2.50mm
EDG1: MSX_CON; msx-con-MSXCART
J2: Conn_02x08_Odd_Even; PinHeader_2x08_P2.54mm_Vertical
U1: 74LS32; DIP-14_W7.62mm_Socket
U2: 74LS688; DIP-20_W7.62mm_Socket
U3, U4: 74LS670; DIP-16_W7.62mm_Socket
U5: SST39SF040; DIP-32_W15.24mm_Socket

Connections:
A0: EDG1.A0, J2.8, U5.12 (A0)
A1: EDG1.A1, U2.2 (P0), U5.11 (A1)
A2: EDG1.A2, U2.4 (P1), U5.10 (A2)
A3: EDG1.A3, U2.6 (P2), U5.9 (A3)
A4: EDG1.A4, U2.17 (P7), U5.8 (A4)
A5: EDG1.A5, U2.8 (P3), U5.7 (A5)
A6: EDG1.A6, U2.11 (P4), U5.6 (A6)
A7: EDG1.A7, U2.13 (P5), U5.5 (A7)
A8: EDG1.A8, U5.27 (A8)
A9: EDG1.A9, U5.26 (A9)
A10: EDG1.A10, U5.23 (A10)
A11: EDG1.A11, U5.25 (A11)
A12: EDG1.A12, U5.4 (A12)
A13: EDG1.A13, U3.4 (Rb), U3.13 (Wb), U4.4 (Rb), U4.13 (Wb)
A15: EDG1.A15, U3.5 (Ra), U3.14 (Wa), U4.5 (Ra), U4.14 (Wa)
BUSDIR_: EDG1./BUSDIR (~BUSDIR), U1.6
CS_: J2.6, U1.4, U2.19 (P=R)
D0: EDG1.D0, J2.15, U3.15 (D1), U5.13 (D0)
D1: EDG1.D1, J2.13, U3.1 (D2), U5.14 (D1)
D2: EDG1.D2, J2.11, U3.2 (D3), U5.15 (D2)
D3: EDG1.D3, J2.9, U3.3 (D4), U5.17 (D3)
D4: EDG1.D4, J2.7, U4.15 (D1), U5.18 (D4)
D5: EDG1.D5, J2.5, U4.1 (D2), U5.19 (D5)
D6: EDG1.D6, J2.3, U4.2 (D3), U5.20 (D6)
D7: EDG1.D7, J2.1, U4.3 (D4), U5.21 (D7)
GND: C1.2, C2.2, C3.2, C4.2, C5.2, EDG1.GND1 (GND), EDG1.GND2 (GND), J2.14, J2.16, U1.1, U1.2, U1.7 (GND), U1.9, U1.10, U2.1 (G), U2.3 (R0), U2.5 (R1), U2.7 (R2), U2.9 (R3), U2.10 (GND), U2.12 (R4), U2.14 (R5), U2.16 (R6), U3.8 (GND), U3.11 (~RD), U4.8 (GND), U4.11 (~RD), U5.16 (GND)
IORQ_: EDG1./IORQ (~IORQ), U2.15 (P6)
unnamed: EDG1.SW1, EDG1.SW2
unnamed: U1.11, U3.12 (~WR)
unnamed: U3.6 (Q4), U5.2 (A16)
unnamed: U3.7 (Q3), U5.3 (A15)
unnamed: U3.9 (Q2), U5.29 (A14)
unnamed: U3.10 (Q1), U5.28 (A13)
unnamed: U4.9 (Q2), U5.1 (A18)
unnamed: U4.10 (Q1), U5.30 (A17)
RD_: EDG1./RD (~RD), J2.4, U1.5, U5.22 (CE)
SLTSL_: EDG1./SLTSL (~SLTSL), U1.13, U5.24 (OE)
VCC: C1.1, C2.1, C3.1, C4.1, C5.1, EDG1.+5V1 (+5V), EDG1.+5V2 (+5V), J2.12, U1.14 (VCC), U2.18 (R7), U2.20 (VCC), U3.16 (VCC), U4.16 (VCC), U5.32 (VCC)
WR_: EDG1./WR (~WR), J2.2, U1.12, U5.31 (PGM)

Board: 2 copper layers, 12 parts (0 on the bottom side), 39 nets, no tracks yet.

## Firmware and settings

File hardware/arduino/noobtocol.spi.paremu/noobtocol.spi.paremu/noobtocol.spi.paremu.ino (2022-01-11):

#include <SPI.h>

#define CH376_CMD_GET_IC_VER      0x01
#define CH_CMD_ENTER_SLEEP        0x03
#define CH375_CMD_RESET_ALL       0x05
#define CH375_CMD_CHECK_EXIST     0x06
#define CH375_CMD_SET_USB_ADDR    0x13
#define CH375_CMD_SET_USB_MODE    0x15
#define CH_CMD_SET_EP0_RX         0x18
#define CH_CMD_SET_EP0_TX         0x19
#define CH_CMD_SET_EP1_RX         0x1a
#define CH_CMD_SET_EP1_TX         0x1b
#define CH_CMD_SET_EP2_RX         0x1c
#define CH_CMD_SET_EP2_TX         0x1d
#define CH375_CMD_GET_STATUS      0x22
#define CH375_CMD_UNLOCK_USB      0x23
#define CH375_CMD_RD_USB_DATA     0x27
#define CH375_CMD_RD_USB_DATA_UNLOCK     0x28
#define CH_CMD_WR_EP0             0x29 // DATA3
#define CH_CMD_WR_EP1             0x2A // DATA5
#define CH_CMD_WR_EP2             0x2B // DATA7
#define CH375_CMD_WR_HOST_DATA    0x2C
#define CH376_CMD_CLR_STALL       0x41
#define CH375_CMD_ISSUE_TKN_X     0x4E
#define CH_CMD_SET_REGISTER       0x0b
#define CH_CMD_GET_REGISTER       0x0a
#define CH_CMD_DELAY_100US        0x0f
#define CH375_CMD_GET_DESCR       0x46
#define CH_CMD_TEST_CONNECT       0x16
#define CH_CMD_SET_FILE_NAME      0x2f
#define CH_CMD_DISK_CONNECT       0x30
#define CH_CMD_DISK_MOUNT         0x31
#define CH_CMD_FILE_OPEN          0x32
#define CH_CMD_FILE_CLOSE         0x36
#define CH_CMD_FILE_ENUM_GO       0x33
#define CH_CMD_BYTE_READ          0x3a
#define CH_CMD_BYTE_RD_GO         0x3b
#define CH_CMD_BYTE_WRITE         0x3c
#define CH_CMD_BYTE_WR_GO         0x3d
#define CH_CMD_DIR_CREATE         0x40
#define CH_CMD_FILE_CREATE        0x34
#define CH_CMD_WR_REQ_DATA        0x2d
#define CH_CMD_DIR_INFO_READ      0x37
#define CH_CMD_BYTE_LOCATE        0x39
#define CH_CMD_FILE_ERASE         0x35

// return codes
#define CH_ST_RET_SUCCESS         0x51
#define CH_ST_RET_ABORT           0x5F

int ledPin = 11;
int intPin = 5;
int misoPin = 3;

int bytes_following;
bool extended_command;
bool zero_ended_command;
bool wait_for_operation_status;
//bool cmd_get_status;
//uint8_t lastStatus;

void setup() {
  // initialize SPI pins
  pinMode(SS, OUTPUT);
  digitalWrite(SS, HIGH);
  SPI.begin ();
  
  // initialize Teensy USB serial
  Serial.begin(0); // baudrate is always maximum usb bus speed 12Mbit/sec

  // initialize LED
  pinMode (ledPin,OUTPUT);
  digitalWrite (ledPin, LOW);

  //lastStatus = 0xff;
}


void beginCmd (byte cmd)
{
  extended_command = false;
  zero_ended_command = false;
  wait_for_operation_status = false;
  //cmd_get_status = false;
  
  switch (cmd) 
  {
    case CH_CMD_ENTER_SLEEP:        bytes_following = 1;
                                    break;   
    case CH375_CMD_CHECK_EXIST:     bytes_following = 3;
                                    break;
    case CH375_CMD_SET_USB_MODE:    wait_for_operation_status = true;
                                    break;
    case CH375_CMD_SET_USB_ADDR:    bytes_following = 2;
                                    break;
    case CH375_CMD_WR_HOST_DATA:    bytes_following = 2;
                                    extended_command = true;
                                    break; 
    case CH_CMD_SET_EP0_RX:         bytes_following = 2;
                                    break;
    case CH_CMD_SET_EP0_TX:         bytes_following = 2;
                                    break;
    case CH_CMD_SET_EP1_RX:         bytes_following = 2;
                                    break;
    case CH_CMD_SET_EP1_TX:         bytes_following = 2;
                                    break;
    case CH_CMD_SET_EP2_RX:         bytes_following = 2;
                                    break;
    case CH_CMD_SET_EP2_TX:         bytes_following = 2;
                                    break;
    case CH_CMD_WR_EP0:             bytes_following = 2;
                                    extended_command = true;
                                    break;  
    case CH_CMD_WR_EP1:             bytes_following = 2;
                                    extended_command = true;
                                    break;  
    case CH_CMD_WR_EP2:             bytes_following = 2;
                                    extended_command = true;
                                    break;                                                                                            
    case CH375_CMD_GET_STATUS:      bytes_following = 2;
                                    //cmd_get_status = true;
                                    break; 
    case CH375_CMD_ISSUE_TKN_X:     bytes_following = 3;
                                    break;           
    case CH376_CMD_GET_IC_VER:      bytes_following = 2;
                                    break;
    case CH376_CMD_CLR_STALL:       bytes_following = 2;
                                    break;
    case CH375_CMD_RD_USB_DATA:     bytes_following = 2;
                                    extended_command = true;
                                    break;
    case CH375_CMD_RD_USB_DATA_UNLOCK:     
                                    bytes_following = 2;
                                    extended_command = true;
                                    break;
    case CH_CMD_SET_REGISTER:       bytes_following = 3;
                                    break;
    case CH_CMD_GET_REGISTER:       bytes_following = 3;
                                    break;        
    case CH_CMD_DELAY_100US:        bytes_following = 2;
                                    break;
    case CH375_CMD_GET_DESCR:       bytes_following = 2;
                                    break;         
    case CH_CMD_TEST_CONNECT:       bytes_following = 2;
                                    break;   
    case CH_CMD_DISK_CONNECT:       bytes_following = 1;
                                    break;   
    case CH_CMD_DISK_MOUNT:         bytes_following = 1;
                                    break;    
    case CH_CMD_FILE_OPEN:          bytes_following = 1;  
                                    break;          
    case CH_CMD_FILE_CLOSE:         bytes_following = 2;  
                                    break;          
    case CH_CMD_FILE_ENUM_GO:       bytes_following = 1;  
                                    break;    
    case CH_CMD_FILE_ERASE:         bytes_following = 1;  
                                    break;                                                                   
    case CH_CMD_SET_FILE_NAME:      bytes_following = 15;
                                    zero_ended_command = true;
                                    break;         
    case CH_CMD_BYTE_READ:          bytes_following = 3;
                                    break;      
    case CH_CMD_BYTE_RD_GO:         bytes_following = 1;
                                    break;  
    case CH_CMD_BYTE_WRITE:         bytes_following = 3;
                                    break;
    case CH_CMD_BYTE_WR_GO:         bytes_following = 1;
                                    break;       
    case CH_CMD_DIR_CREATE:         bytes_following = 1;
                                    break;  
    case CH_CMD_FILE_CREATE:        bytes_following = 1;
                                    break;            
    case CH_CMD_WR_REQ_DATA:        bytes_following = 2;
                                    extended_command = true;
                                    break;         
    case CH_CMD_DIR_INFO_READ:      bytes_following = 2;
                                    break;         
    case CH_CMD_BYTE_LOCATE:        bytes_following = 5;
                                    break;                
    case CH375_CMD_UNLOCK_USB:      bytes_following = 1;
                                    break;                                                                                                                                                                                                                       
    default:                        bytes_following = 1;  
                                    break;
  }
  digitalWrite(SS, LOW);  
  digitalWrite (ledPin, HIGH);
}
void checkEndCmd (byte value)
{
  if (zero_ended_command && value==0)
  {
    bytes_following=0;
    digitalWrite(SS, HIGH);
    digitalWrite (ledPin, LOW);
    return; 
  }
  if (wait_for_operation_status && (value==CH_ST_RET_SUCCESS || value==CH_ST_RET_ABORT))
  {
    bytes_following=0;
    digitalWrite(SS, HIGH);
    digitalWrite (ledPin, LOW);
    return;
  }
  if (--bytes_following==0) 
  {
      if (extended_command)
      {
        extended_command = false;
        bytes_following = value;
        if (bytes_following>0)
          return;
      }
      digitalWrite(SS, HIGH);
      digitalWrite (ledPin, LOW);
      return;
  }
}

void writeCommand (byte cmd)
{
  beginCmd (cmd);
  SPI.transfer (cmd);
  checkEndCmd (-1);
}

void writeData (byte data)
{
  SPI.transfer (data);
  checkEndCmd (data);
}

byte readData ()
{
  byte data = SPI.transfer (0);
  checkEndCmd (data);
/*
  if (cmd_get_status && lastStatus!=0xff)
  {
    data = lastStatus;
    lastStatus = 0xff;
  }
*/
  return data;
}

byte readStatus () 
{
  byte data;
  data = digitalRead (intPin)<<7; // INT
  //data = digitalRead (misoPin)<<7; // MISO
  data += 1; // simulated READY bit
/*
  if ((data & 0x80) == 0) // interrupt pulls down to zero
  {
    digitalWrite(SS, LOW);
    SPI.transfer (CH375_CMD_GET_STATUS);
    delayMicroseconds (1);
    lastStatus = SPI.transfer (0);
    digitalWrite(SS, HIGH);
  }
  else
    lastStatus = 0xff;
*/    
  return data;
}

void loop() 
{
  byte data;
  int length;
  int i;
  byte *inbytes,*outbytes;

  // loop when no serial request received
  if (Serial.available() == 0) 
    return;

  // process serial request
  data = ReadByteFromSerial();
  switch (data)
  {
  case 1: //Write command
    data = ReadByteFromSerial();
    writeCommand(data);
    break;
  case 2: //Read status
    data = readStatus ();
    WriteByteToSerial(data);
    break;
  case 3: //Write data
    data = ReadByteFromSerial();
    writeData(data);
    break;
  case 4: //Read data
    data = readData();
    WriteByteToSerial(data);
    break;
  case 6: //Read multiple data
    length = ReadByteFromSerial();
    inbytes = (byte*) malloc (length);
    for (i = 0; i < length; i++)
      inbytes[i] = readData();
    Serial.write (inbytes,length);
    Serial.send_now();
    free (inbytes);
    break;
  case 7: //Write multiple data
    length = ReadByteFromSerial();
    outbytes = (byte*) malloc (length);
    for (i = 0; i < length; i++)
    {
      outbytes[i] = ReadByteFromSerial();
      writeData(outbytes[i]);
    }
    free (outbytes);
    break;    
  case 10: // block benchmark
    for (i=0;i<512*10;i++) 
    {
      Serial.write (0xAA);
    }
    break;
  case 11: // roundtrip benchmark
    Serial.write (Serial.read ());
    break;
  default:
    while (Serial.available() >= 0) Serial.read();
  }
}

byte ReadByteFromSerial()
{
   while (Serial.available() == 0);
   return Serial.read();
}

void WriteByteToSerial(byte data)
{
  while (Serial.availableForWrite() == 0);
  Serial.write(data);
}

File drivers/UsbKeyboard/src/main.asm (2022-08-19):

;
; main.ASM - USB HID keyboard driver that uses the MSX USB Unapi driver.
; Copyright (c) 2020 Mario Smit (S0urceror)
; 
; This program is free software: you can redistribute it and/or modify  
; it under the terms of the GNU General Public License as published by  
; the Free Software Foundation, version 3.
;
; This program is distributed in the hope that it will be useful, but 
; WITHOUT ANY WARRANTY; without even the implied warranty of 
; MERCHANTABILITY or FITNESS FOR A PARTICULAR PURPOSE. See the GNU 
; General Public License for more details.
;
; You should have received a copy of the GNU General Public License 
; along with this program. If not, see <http://www.gnu.org/licenses/>.
;

ARG:		equ	#F847
EXTBIO:		equ	#FFCA
RSLREG:     equ 0138h
ENASLT:     equ 0024h
EXPTBL:	    EQU	0FCC1H		;slot is expanded or not
H.CHGE:     EQU 0FDC2h	

; major and minor version number of MSXUSB UNAPI that we need
UNAPI_P:    equ  0
UNAPI_S:    equ  3

    include "msxusbunapi.asm"

    org 0100h
BEGIN:
START_BASIC:
    ld hl,TXT_WELCOME
    call PRINT_DOS
    ; check if EXTBIO is set (before we try UNAPI and Memory Mapper calls)
    ld a, (0FB20h)
    and 00000001b
    ret z
    ; check if the MSX USB UNAPI is available
    call GET_UNAPI_MSXUSB
    push af
    ld hl,TXT_MSXUSB_NOT_FOUND
    call c, PRINT_DOS
    pop af 
    ret c
    ; check, connect, getdescriptors
    call USB_CHECK_ADAPTER
    ret c
    call USB_CONNECT_DEVICE
    push af
    ld hl,TXT_DEVICE_NOT_CONNECTED
    call z, PRINT_DOS
    pop af 
    ret z
    ; A holds the number of connected devices, try all of them
    ld d, 1 ; start with device number 1
    ld b, a
_AGAIN_:
    push bc, de
    call USB_GET_DESCRIPTORS
    ; check if USB HID is connected
    call USB_CHECK_HID
    pop de, bc
    jr nc, _FOUND_
    inc d
    djnz _AGAIN_
    ld hl, TXT_HID_CHECK_NOK
    call PRINT_DOS
    ret
_FOUND_:
    ld a, d
    ld (DEVICE_ADDRESS),a
    ld hl, TXT_HID_CHECK_OKAY
    call PRINT_DOS
    ; allocate a segment in the mapper
    call ALLOC_SEG
    push af
    ld hl,TXT_SEG_NOT_ALLOCATED
    call c, PRINT_DOS
    pop af 
    ret c
    ; get pointer to scratch_area
    call USB_GET_SCRATCH
    ; copy the TSR part to the new segment
    call COPY_TSR_SEG
    ret c
    ; instruct the keyboard to start sending keystrokes
    call USB_HID_KEYBOARD_START
    ret c
    ; hook the TSR to H.CHGE
    call HOOK_TSR_HCHGE
    ret c
    
    ret 

GET_UNAPI_MSXUSB:
    ; copy our ID to ARG
    ld	hl,UNAPI_ID
	ld	de,ARG
	ld	bc,15
	ldir
    ; get the number of instances of MSXUSB
	xor	a
	ld	b,0
	ld	de,#2222
	call EXTBIO ; Returns B=nr.instances
	ld	a, b
	or	a
	jp	z,ERROR
    ; get our UNAPI_ENTRY
    ld a, b ; use last implementation
    ld  de, #2222
    call EXTBIO ;Returns A=slot, B=segment, HL=entry point
    ld  (IMP_SLOT),a
    ld  (IMP_ENTRY),hl
    ; we do not support MSXUSB on memory mapper
    ld  a,b
    cp  0FFh
    jp  nz,ERROR
    ; we do not support page 3
    ld  a,(IMP_ENTRY+1)
    and  10000000b
    jp  nz,ERROR
    ; okay MSXUSB in ROM, check if it supports our version
    ld a, USB_INFO
    call UNAPI_ENTRY
    ld a, d
    cp UNAPI_P
    jp nz, ERROR
    ld a, e
    cp UNAPI_S
    jp nz, ERROR
    ; all fine
    ld hl, TXT_MSXUSB_FOUND
    call PRINT_DOS
    or a
    ret

USB_CHECK_ADAPTER:
    ld a, USB_CHECK
    call UNAPI_ENTRY
    jp c, ERROR

    ld hl, TXT_ADAPTER_OKAY
    call PRINT_DOS
    or a
    ret 
    
USB_CONNECT_DEVICE:
    ld a, USB_CONNECT
    call UNAPI_ENTRY
    and a
    jp z, ERROR

    push af
    ld hl, TXT_DEVICE_CONNECTED
    call PRINT_DOS
    pop af
    ret 
    
USB_GET_DESCRIPTORS:
    ld hl, DESCRIPTORS
    ld a, USB_GETDESCRIPTORS
    call UNAPI_ENTRY
    jp c, ERROR
    ret

USB_GET_SCRATCH:
    ld bc, 0
    ld a, USB_CONTROL_PACKET
    call UNAPI_ENTRY
    ld (SCRATCH_AREA),hl
    ret

USB_HID_KEYBOARD_START:
    ; found HID keyboard?
    call GET_DESCR_CONFIGURATION ; returns configuration_value in A and Cy to indicate error
    ret c
    ; set configuration 
    push af
    ld a, (KEYBOARD_MAX_PACKET_SIZE)
    ld b, a
    ld a, (DEVICE_ADDRESS)
    ld d, a
    pop af
    call CH_SET_CONFIGURATION
    ret c
    ; set protocol (BOOT_PROTOCOL,keyboard_interface)
    ld a, (DEVICE_ADDRESS)
    ld d, a
    ld a, (KEYBOARD_MAX_PACKET_SIZE)
    ld b, a
    ld a, (KEYBOARD_INTERFACENR)
    ld e, a ; interface number
    ld a, CH_BOOT_PROTOCOL
    call CH_SET_PROTOCOL
    ret c
    ; set idle (0x80)
    ld a, (DEVICE_ADDRESS)
    ld d, a
    ld a, (KEYBOARD_MAX_PACKET_SIZE)
    ld b, a
    ld a, (KEYBOARD_INTERFACENR)
    ld e, a ; interface number
    ld a, 80h 
    ld c, 0 ; report id
    call CH_SET_IDLE
    ret c
    ret

; --------------------------------------
; GET_DESCR_CONFIGURATION
;
; Input: (none)
; Output: Cy=0 no error, Cy=1 error
;         A = configuration id
GET_DESCR_CONFIGURATION:
    ld ix, DESCRIPTORS
    ld a, (ix+DEVICE_DESCRIPTOR.bNumConfigurations)
    cp 1
    jr nz,_ERR_GET_DESCR_CONFIGURATION ; only 1 configuration allowed
    ld bc, DEVICE_DESCRIPTOR
    add ix, bc
    ; ix now pointing to first (and only) configuration descriptor
    ld a, (ix+CONFIG_DESCRIPTOR.bConfigurationvalue)
    or a ; reset Cy
    ret
_ERR_GET_DESCR_CONFIGURATION:
    scf
    ret
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

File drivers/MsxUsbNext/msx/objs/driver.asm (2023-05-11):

;--------------------------------------------------------
; File Created by SDCC : free open source ANSI-C Compiler
; Version 4.0.0 #11528 (Linux)
;--------------------------------------------------------
	.module driver
	.optsdcc -mz80
	
;--------------------------------------------------------
; Public variables in this module
;--------------------------------------------------------
	.globl _read_or_write_sector
	.globl _caps_flash
	.globl _get_device_status
	.globl _get_device_info
	.globl _get_lun_info
	.globl _get_drive_config
	.globl _get_nr_drives_boottime
	.globl _onCallMOUNTDSK
	.globl _init_driver
	.globl _get_workarea_size
	.globl _interrupt
	.globl _get_workarea
	.globl _read_write_disk_sectors
	.globl _read_write_file_sectors
	.globl _usbdisk_select_dsk_file
	.globl _usbdisk_autoexec_dsk
	.globl _usbdisk_init
	.globl _hal_init
	.globl _puts
;--------------------------------------------------------
; special function registers
;--------------------------------------------------------
;--------------------------------------------------------
; ram data
;--------------------------------------------------------
	.area _DATA
;--------------------------------------------------------
; ram data
;--------------------------------------------------------
	.area _INITIALIZED
;--------------------------------------------------------
; absolute external ram data
;--------------------------------------------------------
	.area _DABS (ABS)
;--------------------------------------------------------
; global & static initialisations
;--------------------------------------------------------
	.area _HOME
	.area _GSINIT
	.area _GSFINAL
	.area _GSINIT
;--------------------------------------------------------
; Home
;--------------------------------------------------------
	.area _HOME
	.area _HOME
;--------------------------------------------------------
; code
;--------------------------------------------------------
	.area _CODE
;driver.c:11: workarea_t* get_workarea() __z88dk_fastcall __naked
;	---------------------------------
; Function get_workarea
; ---------------------------------
_get_workarea::
;driver.c:26: __endasm;
	GWORK	.equ 0x4045
	CALBNK	.equ 0x4042
	push	ix
	xor	a
	ex	af,af' ;'
	xor	a
	LD	ix,#GWORK
	call	CALBNK
	ld	l,0(ix)
	ld	h,1(ix)
	pop	ix
	ret
;driver.c:27: } 
;driver.c:35: void interrupt ()
;	---------------------------------
; Function interrupt
; ---------------------------------
_interrupt::
;driver.c:40: }
	ret
;driver.c:55: uint16_t get_workarea_size (uint8_t reduced_drive_count,uint8_t nr_available_drives)
;	---------------------------------
; Function get_workarea_size
; ---------------------------------
_get_workarea_size::
;driver.c:61: return sizeof (workarea_t);
	ld	hl, #0x0002
;driver.c:62: }
	ret
;driver.c:86: void init_driver (uint8_t reduced_drive_count,uint8_t nr_allocated_drives)
;	---------------------------------
; Function init_driver
; ---------------------------------
_init_driver::
	push	ix
;driver.c:92: hal_init ();
	call	_hal_init
;driver.c:93: workarea_t* workarea = get_workarea();
	call	_get_workarea
;driver.c:94: usbdisk_init ();
	push	hl
	call	_usbdisk_init
	pop	bc
;driver.c:95: workarea->disk_change = true;
	ld	l, c
	ld	h, b
	inc	hl
	ld	(hl), #0x01
;driver.c:96: if (usbdisk_autoexec_dsk()==true)
	push	bc
	call	_usbdisk_autoexec_dsk
	pop	bc
	bit	0, l
	jr	Z,00102$
;driver.c:97: workarea->mount_mode = 2;
	ld	a, #0x02
	ld	(bc), a
	jr	00103$
00102$:
;driver.c:99: workarea->mount_mode = usbdisk_select_dsk_file ("/");
	push	bc
	ld	hl, #___str_0
	push	hl
	call	_usbdisk_select_dsk_file
	pop	af
	ld	a, l
	pop	bc
	ld	(bc), a
00103$:
;driver.c:100: switch (workarea->mount_mode)
	ld	a, (bc)
	cp	a, #0x01
	jr	Z,00105$
	sub	a, #0x02
	jr	NZ,00106$
;driver.c:103: printf ("+Opened disk image\r\n");
	ld	hl, #___str_2
	push	hl
	call	_puts
	pop	af
;driver.c:104: break;
	jr	00108$
;driver.c:105: case 1:
00105$:
;driver.c:106: printf ("+Full disk mode\r\n");
	ld	hl, #___str_4
	push	hl
	call	_puts
	pop	af
;driver.c:107: break;
	jr	00108$
;driver.c:108: default:
00106$:
;driver.c:109: printf ("+Using floppy disk\r\n");
	ld	hl, #___str_6
	push	hl
	call	_puts
	pop	af
;driver.c:111: }   
00108$:
;driver.c:112: }
	pop	ix
	ret
___str_0:
	.ascii "/"
	.db 0x00
___str_2:
	.ascii "+Opened disk image"
	.db 0x0d
	.db 0x00
___str_4:
	.ascii "+Full disk mode"
	.db 0x0d
	.db 0x00
___str_6:
	.ascii "+Using floppy disk"
	.db 0x0d
	.db 0x00
;driver.c:114: void onCallMOUNTDSK ()
;	---------------------------------
; Function onCallMOUNTDSK
; ---------------------------------
_onCallMOUNTDSK::
;driver.c:116: hal_init ();
	call	_hal_init
;driver.c:117: workarea_t* workarea = get_workarea();
	call	_get_workarea
;driver.c:118: workarea->disk_change = true;
	ld	c,l
	ld	b,h
	inc	hl
	ld	(hl), #0x01
;driver.c:119: usbdisk_init ();
	push	bc
	call	_usbdisk_init
	ld	hl, #___str_7
	push	hl
	call	_usbdisk_select_dsk_file
	pop	af
	ld	a, l
	pop	bc
	ld	(bc), a
;driver.c:121: switch (workarea->mount_mode)
	push	af
	ld	a, (bc)
	ld	c, a
	pop	af
	dec	a
	jr	Z,00102$
	ld	a, c
	sub	a, #0x02
	jr	NZ,00103$
;driver.c:124: printf ("+Opened disk image\r\n");
	ld	hl, #___str_9
	push	hl
	call	_puts
	pop	af
;driver.c:125: break;
	ret
;driver.c:126: case 1:
00102$:
;driver.c:127: printf ("+Full disk mode\r\n");
	ld	hl, #___str_11
	push	hl
	call	_puts
	pop	af
;driver.c:128: break;
	ret
;driver.c:129: default:
00103$:
;driver.c:130: printf ("+Using floppy disk\r\n");
	ld	hl, #___str_13
	push	hl
	call	_puts
	pop	af
;driver.c:132: }   
;driver.c:133: }
	ret
___str_7:
	.ascii "/"
	.db 0x00
___str_9:
	.ascii "+Opened disk image"
	.db 0x0d
	.db 0x00
___str_11:
	.ascii "+Full disk mode"
	.db 0x0d
	.db 0x00
___str_13:
	.ascii "+Using floppy disk"
	.db 0x0d
	.db 0x00
;driver.c:145: uint8_t get_nr_drives_boottime (uint8_t reduced_drive_count,uint8_t dos_mode)
;	---------------------------------
; Function get_nr_drives_boottime
; ---------------------------------
_get_nr_drives_boottime::
;driver.c:151: workarea_t* workarea = get_workarea();
	call	_get_workarea
;driver.c:152: if (workarea->mount_mode==0)
	ld	a, (hl)
;driver.c:153: return 0;
	or	a,a
	jr	NZ,00102$
	ld	l,a
	ret
00102$:
;driver.c:155: return 1; // 1 drive requested
	ld	l, #0x01
;driver.c:156: }
	ret
;driver.c:168: uint16_t get_drive_config (uint8_t relative_drive_number,uint8_t dos_mode)
;	---------------------------------
; Function get_drive_config
; ---------------------------------
_get_drive_config::
;driver.c:174: return 0x0101; // device 1, lun 1
	ld	hl, #0x0101
;driver.c:175: }
	ret
;driver.c:213: uint8_t get_lun_info (uint8_t nr_lun,uint8_t nr_device,luninfo_t* luninfo)
;	---------------------------------
; Function get_lun_info
; ---------------------------------
_get_lun_info::
;driver.c:219: if (nr_lun==1 && nr_device==1)
	ld	iy, #2
	add	iy, sp
	ld	a, 0 (iy)
	dec	a
	jr	NZ,00102$
	inc	iy
	ld	a, 0 (iy)
	dec	a
	jr	NZ,00102$
;driver.c:221: memset (luninfo,0,sizeof (luninfo_t));
	inc	iy
	ld	l, 0 (iy)
	ld	h, 1 (iy)
	ld	b, #0x0c
00120$:
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

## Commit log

2020-01-21 Initial combined MSX USB release
    [MSX USB Drive.kicad_pcb, MSX USB Drive.sch]
2020-02-16 Implemented JumpTable within UNAPI driver
2020-02-22 UNAPI compatible keyboard driver
2020-03-26 squashed bugs and made it faster
    [ch376s.asm, main.asm]
2020-03-26 Updated schematics with the right gate in 74LS32
2020-03-26 Added A13,A15 and updated IC numbering
    [MSX USB Drive.sch]
2020-03-26 PCB first attempt
    [MSX USB Drive.sch]
2020-04-06 CPLD version of PCB + verilog code
    [MSX USB Drive-B_Cu.gbr, MSX USB Drive-B_Mask.gbr, MSX USB Drive-B_Paste.gbr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]
2020-04-11 combined drivers, updated reset
    [ch376s.asm, driver.asm]
2020-04-13 Combined USB Host and Nextor driver
2020-04-13 wait timers implemented
2020-04-13 fixed bugs in Basic extensions
    [driver.asm]
2020-04-19 Bugfixes after merge of USBHost and Nextor
    [ch376s.asm, driver.asm, main.asm]
2020-05-14 CPLD PCB Verilog + Flash software works
    [MSX USB Drive.kicad_pcb, MSX USB Drive.sch, verilog.psm]
2020-06-04 UsbStorage low-level driver completed
2020-06-15 Updated driver inititialisation + bugfixes
2020-06-16 Discrete PCB discontinued, flash changed AM29F040
    [MSX USB Drive.kicad_pcb, MSX USB Drive.sch]
2020-10-18 uIP + various bug fixes
    [ch376s.asm, driver.asm]
2021-03-27 SPI and MiSTer support
2021-03-27 normal int's for when not SPI
2021-03-30 emulate parallel interface via SPI
2021-04-06 noobtocol SPI emulating parallel
2021-05-30 flash support AMIC, new v1.0 Gerbers
    [MSX USB Drive-B_Cu.gbr, MSX USB Drive-B_Mask.gbr, MSX USB Drive-B_Paste.gbr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]
2021-08-31 Various bugfixed, updated documentation
    [MSX USB Drive.xlsx]
2022-01-11 Stability improvements, STALL handling
    [ch376s.asm, noobtocol.parallel.ino, noobtocol.spi.paremu.ino]
2022-01-31 stability, first release msxusbnext
    [ch376s.asm, driver.asm]
2022-02-06 CALL mountdsk for MSXUSBNext
2022-03-13 Fixed STALL recovery
2022-08-19 Fixed bug raised by @christianoag
    [altera-usb-blaster.cfg]
2022-09-11 Nextor bug patched in DOS1 mode, page 1 RW
    [driver.asm]
2022-11-27 added rev4 pcb by @cristianoag
    [MSX USB Drive-B_Cu.gbr, MSX USB Drive-B_Mask.gbr, MSX USB Drive-B_Paste.gbr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]
2022-11-27 added flash-switching by @cristianoag
    [altera-usb-blaster.cfg, verilog.psm]
2022-11-27 Updated readme to mention rev4 PCB by @cristianoag
2023-01-13 small changes to the PCB (holes) and cpld code
    [MSX USB Drive-B_Cu.gbr, MSX USB Drive-B_Mask.gbr, MSX USB Drive-B_Paste.gbr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]
